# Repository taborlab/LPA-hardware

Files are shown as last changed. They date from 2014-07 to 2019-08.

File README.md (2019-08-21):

# LPA - The Light Plate Apparatus

### Introduction

The LPA is a device capable of illuminating each well of a 24-well plate with two independently time-varying light signals. An electronic board based on the Atmega328 microcontroller reads light intensity values from an SD card and controls the LEDs responsible for illumination.

This repository contains source files, needed to modify the LPA's design. To obtain the minimum necessary files for building and using an LPA, click [here](https://github.com/taborlab/LPA-hardware/releases/download/v1.1/lpa.zip).

If you use the LPA in your research, please cite [Gerhardt K.P., et al. "An open-hardware platform for optogenetics and photobiology." Scientific Reports 6 (2016)](https://www.nature.com/articles/srep35363) and/or [Gerhardt K.P., Castillo-Hair S.M., and Tabor J.T. "DIY optogenetics: Building, programming, and using the Light Plate Apparatus." Methods Enzymol. (2019)](https://www.sciencedirect.com/science/article/pii/S0076687919301338)

### Documentation

The documentation website for the LPA can be found in http://taborlab.github.io/LPA-hardware/.

### Contents:
* BOM: Bill of materials for circuit board and chassis.
* CAD Files: Design files for the different parts of the LPA. This folder contains:
  * 3D Printed Parts: Models of the structural 3D-printed elements of the LPA, in SolidWorks format.
  * Circuit Board: Schematics and layout of the electronic board, in KiCAD format.
  * Gaskets: Diagrams of the rubber gaskets, in DXF (AutoCAD) format.
* Firmware: Source files of the microcontroller's firmware in C++, organized as an Atmel Studio project.
* Calibration: Image analysis script for imager-based LED calibration, in matlab format, and examples.

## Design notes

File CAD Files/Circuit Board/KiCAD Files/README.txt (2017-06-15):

Folder contents
===============

Main files
----------
- lpa.pro : KiCAD project
- lpa.sch : Main schematic diagram
- tlcs_1-3.sch: LED driver schematic diagram
- lpa.kicad_pcb : PCB layout diagram

Libraries
---------
- libraries : folder with schematic diagram part libraries
- LPA_parts.pretty: folder with PCB layout diagram part libraries
- fp-lib-table: file listing the PCB layout diagram part libraries used by this project
- lpa-cache.lib: Part library cache, from which parts can be loaded if not found in the standard libraries.

How to use
==========
Electronic CAD files were created on KiCAD, which can be downloaded from http://kicad-pcb.org/.
To see the CAD files, open KiCAD, go to File -> Open Project, and select "lpa.pro". KiCAD will show a list of files on its left panel. The most important are lpa.sch (schematic diagram) and lpa.kicad_pcb (printed circuit board (PCB) diagram). Double click on each to open.

About gerber files
==================
Gerber files for production were generated according to these instructions: http://docs.oshpark.com/design-tools/kicad/generating-kicad-gerbers/.

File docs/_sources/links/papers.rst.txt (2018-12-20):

Papers which use LPAs
============================

\P. Ramakrishnan, J.J. Tabor **"Repurposing Synechocystis PCC6803 regulatory tool in E. coli."** *ACS Syn. Biol.* 5(7), 733–740 (2016).

K.P. Gerhardt, E.J. Olson, S.M. Castillo-Hair, L.A. Hartsough, B.P. Landry, F. Ekness, R. Yokoo, E.J. Gomez, P. Ramakrishnan, J. Suh, D.F. Savage, J.J. Tabor **"An open-hardware platform for optogenetics and photobiology."** *Sci. Rep.* 6, 35363 (2016).

E.J. Olson, C.N. Tzouanas, J.J. Tabor **"A photoconversion model for full spectral programming and multiplexing of optogenetic systems."** *Mol. Syst. Biol.* 13(4), 926 (2017).

N.T. Ong, E.J. Olson, J.J. Tabor **"Engineering an E. coli Near-Infrared Light Sensor."** *ACS Syn. Biol.* 7(1), 240–248 (2018).

N.T. Ong, J.J. Tabor **"A miniaturized E. coli green light sensor with high dynamic range."** *Chembiochem.* 19, 1255-1258 (2018).

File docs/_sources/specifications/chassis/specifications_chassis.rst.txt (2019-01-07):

-----------------------------
Chassis
-----------------------------

Detailed photographs of 3D printed LPA parts
------------------------------------------------

.. figure:: chassis_1.png
   :scale: 30%
   :figwidth: 100%

.. figure:: chassis_2.png
   :scale: 30%
   :figwidth: 100%

   Bottom and top perspectives of 3D printed LPA parts are shown.
   These include (a) mounting plate, (b) LED spacer, (c) cell culture plate adapter, and (d) device lid.
   If shaking culture is required, the mounting plate platform holes must be designed for a particular platform.
   The two mounting plates shown were designed for two different shaking platforms.

Photographs of LPA gaskets
------------------------------------------------

.. figure:: gaskets.png
   :scale: 30%
   :figwidth: 100%

   LPA gaskets are laser cut (see Supplementary Method on Laser cutting gaskets) from nitrile sheets (Supplementary Table S6) and prevent light leakage and crosstalk between wells.
   (a) The (i) circuit board, (ii) LED spacer, and (iii) cell culture plate adapter gaskets are shown.
   Gasket names are based on the layer they lay atop.
   Though not necessary, we found it convenient to superglue on the cell culture plate adapter gasket.
   (b) A plate adapter gasket which has been laser cut with patterns centered with wells of the culture plate.

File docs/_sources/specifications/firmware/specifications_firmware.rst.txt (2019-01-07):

Firmware
==========================

Introduction
--------------------------

The LPA firmware is an embedded program written in C for the ATmega328 microcontroller. It performs the following main functions:

  a)	Reads an LPF file from an SD card, connected to the microcontroller via a Serial Peripheral Interface (SPI).
  b)	Reads light intensity (“grayscale”) values from the LPF file.
  c)	Updates the intensity of a set of LEDs under control of TLC5941 drivers, by transferring the appropriate grayscale values via SPI.

The firmware has been divided in different modules that perform separate functions. All the relevant variables inside a module are named as <module_name>_<variable_name>. Functions are named in a similar format. Modules are written such that, when possible, the assignment of hardware resources is defined by a “configuration” step, controlled by a separate config.h file that is included during compilation. This facilitates porting the individual modules to different projects, or transferring this project to a similar microcontroller.

In this section, we will describe the high-level behavior of the firmware main program, the contents of each module, and the config.h file.

States of the Firmware Program
---------------------------------------------

.. figure:: states.png
   :scale: 20%
   :figwidth: 100%

   In this diagram, rounded squares denote states, rounded squares with double edges denote terminal states, and arrows denote transitions. The circle labeled as START denotes the state of the program upon booting.

The LPA will often need to respond differently to the same stimuli, especially under error conditions. This is best managed by modeling the system as a finite state machine, in which the device’s behavior is a function of both the inputs and the current state. In the firmware, the current state is contained in a single variable. Supplementary Table S4 enumerates the different states of the device, and Supplementary Fig. S14 shows the transition diagram between different states. Each pattern displayed by the status LEDs corresponds directly to each state (Supplementary Tables S3 and S4).

TLC5941 Driver module
----------------------------------------

The TLC5941 driver module is available as a separate project (https://github.com/castillohair/Tlc5941_library). This module is heavily based on the “Demystifying the TLC5940” book10, with a few additions to make the library work with the TL5941 instead of the TL5940, the Atmega328 USART module instead of the SPI module, among others. In short, this module incorporates functions to:

-	Initialize the TLC5941
-	Set grayscale values, one at a time or all at once.
-	Change dot correction values, one at a time or all at once.

In addition, several precompiler flags are available to define the pins used to interact with the TLC5941. These can be changed inside “config.h” file without modifying the library’s source code.

MsTimer Module
---------------------------------

The MsTimer (millisecond timer) module incorporates functions to define a timer that calls a set of functions (“callbacks”) periodically, with a period specified in milliseconds. This module uses the Atmega’s Timer1 to generate interrupts via compare events. The module incorporates functions to

-	Initialize the relevant registers of Timer1.
-	Add callbacks and their respective periods in milliseconds.
- Start and stop the module.

StatusLeds Module
----------------------------

The StatusLeds module is a simple module that abstracts the toggling of status LEDs on the board. It incorporates functions to

-	Initialize the pins that control the status LEDs.
-	Set the status of an LED to on or off.
-	Toggle an LED to the opposite state.

SD Card Reading
-------------------------

SD card reading is performed using the Arduino SD card library. For details on how to set the library before compiling, refer to the Supplementary Method on firmware programming.

The config.h File
----------------------

The config.h file should be included during compilation of every file associated with the project. By doing this, preprocessor directives defined in config.h (i.e. #define instructions) replace the ones defined in the modules by default. This allows us to override the default behavior of the module without changing the code, a procedure called “configuration”.

Additionally, the firmware has been made such that an arbitrary number of LEDs in any arrangement is possible. The number of LEDs is specified through the number of LED drivers (Tlc5941_N), whereas the arrangement is specified as a constant array (well2channel). The arrangement corresponding to the 24-well LPA is included by default, but a file called “config_96.h”, which illustrates the configuration for a hypothetical 96-well LPA, is also included.

firmware.cpp
-------------------------

This file contains the main function of the firmware (main()). Other important parts are:

-	Variables dotCorrectionValues[] and grayscaleCalibration[], which store dot correction and grayscale calibration values after reading them from files dc.txt and gcal.txt in the SD card.
-	Definitions of constants corresponding to the states (Supplementary Table S4, all the #define System_<state_name> instructions), a variable containing the current state (System_state), and functions to evaluate the state (System_SetState(), System_IsState() and System_IsNotState()).
-	A function to update the LPA LEDs, UpdateLeds().
-	A function to update the status LEDs based on the current state, UpdateStatusLeds().

In short, the main function does the following:

1.	Initializes the TLC5941 module.
2.	Initializes the MsTimer and the StatusLeds module.
3.	Initializes the SD card module.
4.	Reads and parses both dc.txt and gcal.txt files.
5.	Opens the “program.lpf” file.
6.	Reads the time step size specified in “program.lpf”, and initializes timers with MsTimer so UpdateLeds() is called with the appropriate frequency.
7.	Waits for UpdateLeds() to be called.
8.	Reads a new set of intensity values from the SD card and places them on a buffer, such that UpdateLeds() can send them to the TLC5941s when it is called again.
9.	Repeat from 6 until “program.lpf” file has been read completely.

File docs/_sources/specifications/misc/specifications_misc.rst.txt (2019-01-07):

-----------------------------
Miscellaneous
-----------------------------

LPA power connections
-----------------------------------

.. image:: power_connections.png
   :scale: 30%

The LPA requires a continuous 5V DC power supply and power connections must be reinforced during experiments to prevent movement and mechanical stress, particularly for shaking culture.
Standard laboratory tape can be used as shown to secure power connections and free wires.

Photographs of 3D printed auxiliary parts
------------------------------------------------

.. image:: auxillary.png
   :scale: 30%

The LED socket aligner is used to align and secure LED sockets to the circuit board during soldering (see Supplementary Method on circuit board fabrication and assembly).
(b) The probe adapter is used to position and align the spectrometer probe while making LED intensity measurements (see Supplementary Method on LED calibration).
Top and Bottom versions of the part are used for alignment with Top and Bottom LEDs, respectively.
(c) The flow tube holder holds and spaces flow cytometry tubes with the same geometry as wells from the cell culture plate.
The holder allows easy transfer of samples from the culture plate to flow tubes using a multichannel pipettor (LT12-1200, Ranin).
The part is snapped together and epoxied from three separately printed parts: top rack, bottom rack, and pegs.

Close-up photograph of LED and LED socket friction fit
----------------------------------------------------------

.. image:: led_socket.png
   :scale: 30%

LEDs are positioned, aligned, and held in place by mating with an LED socket (Supplementary Table S1) via friction fit.
This fixture system allows LEDs in the LPA to be easily be installed, removed, and reconfigured.

Photograph and schematic of culture plate used in the LPA
----------------------------------------------------------------

.. image:: culture_plate.png
   :scale: 30%

\(a) Top and bottom views of the 24-well culture plate (AWLS-303008, ArcticWhite LLC) used in the LPA.
\(b) A schematic (adapted from supplier schematic) showing the important dimensions (mm) of the plate.
The original schematic can be requested from ArcticWhite LLC.

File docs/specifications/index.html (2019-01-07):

- Docs »
- Specifications
- View page source

# Specifications¶

Warning

The following specifications describe the LPA v1.0. Changes to later LPA versions are described in the releases section of the github repo.

- Electronics
  - Detailed circuit board photographs
  - Circuit board SD-card reader stage schematic
  - Circuit board microcontroller stage schematic
  - Circuit board LED driver stage schematic
  - Circuit board power stage schematic
- Firmware
  - Introduction
  - States of the Firmware Program
  - TLC5941 Driver module
  - MsTimer Module
  - StatusLeds Module
  - SD Card Reading
  - The config.h File
  - firmware.cpp
- Chassis
  - Detailed photographs of 3D printed LPA parts
  - Photographs of LPA gaskets
- Miscellaneous
  - LPA power connections
  - Photographs of 3D printed auxiliary parts
  - Close-up photograph of LED and LED socket friction fit
  - Photograph and schematic of culture plate used in the LPA

Next Previous

© Copyright 2016, Tabor Lab

Built with Sphinx (http://sphinx-doc.org/) using a theme (https://github.com/rtfd/sphinx_rtd_theme) provided by Read the Docs (https://readthedocs.org).

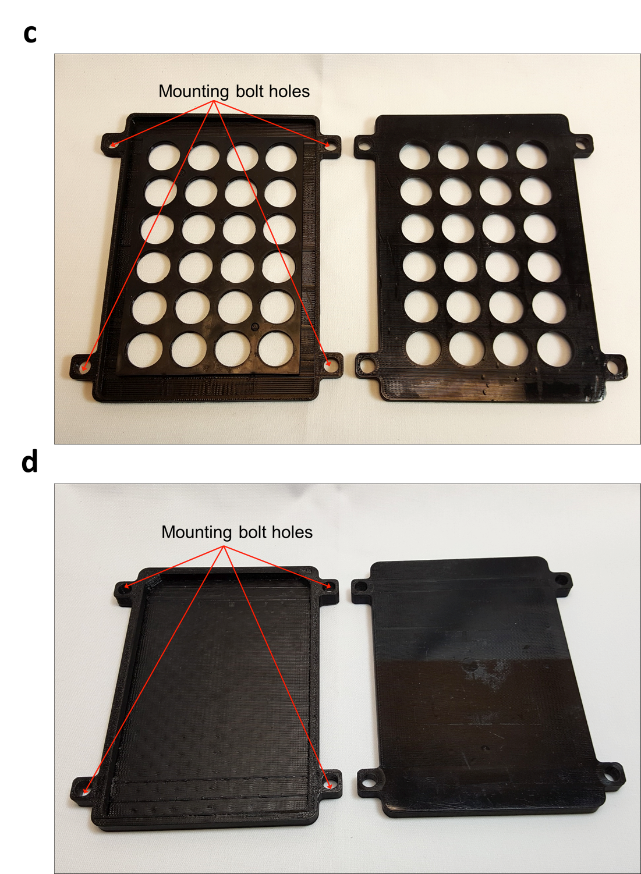
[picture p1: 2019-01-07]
docs/_images/chassis_2.png

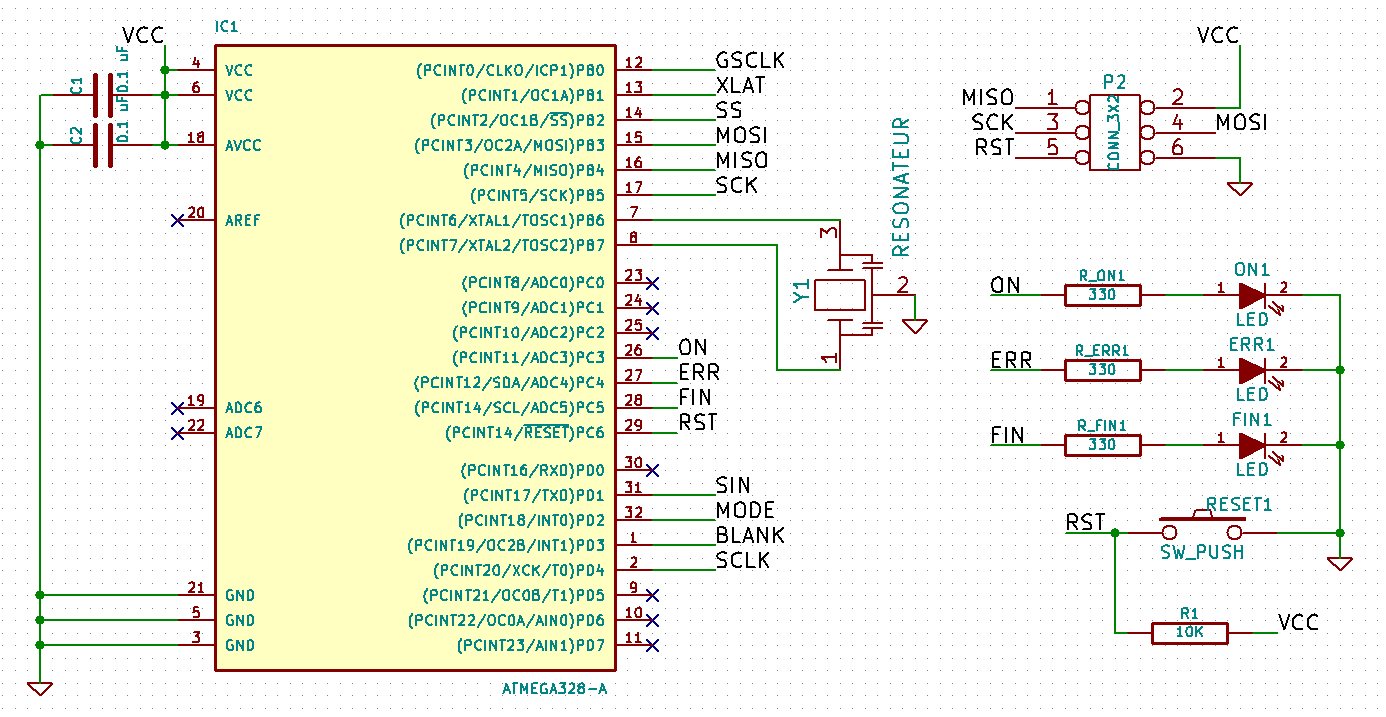
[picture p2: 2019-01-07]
docs/_images/microcontroller.png

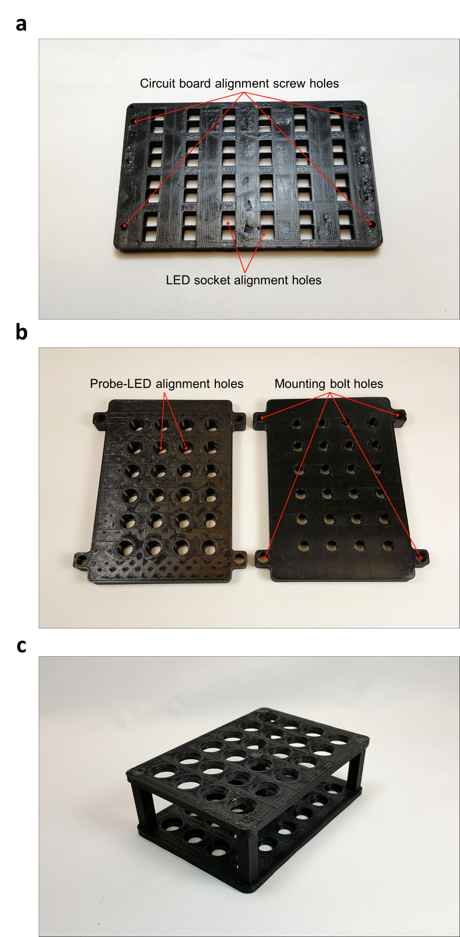
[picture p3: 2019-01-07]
docs/_images/auxillary.png

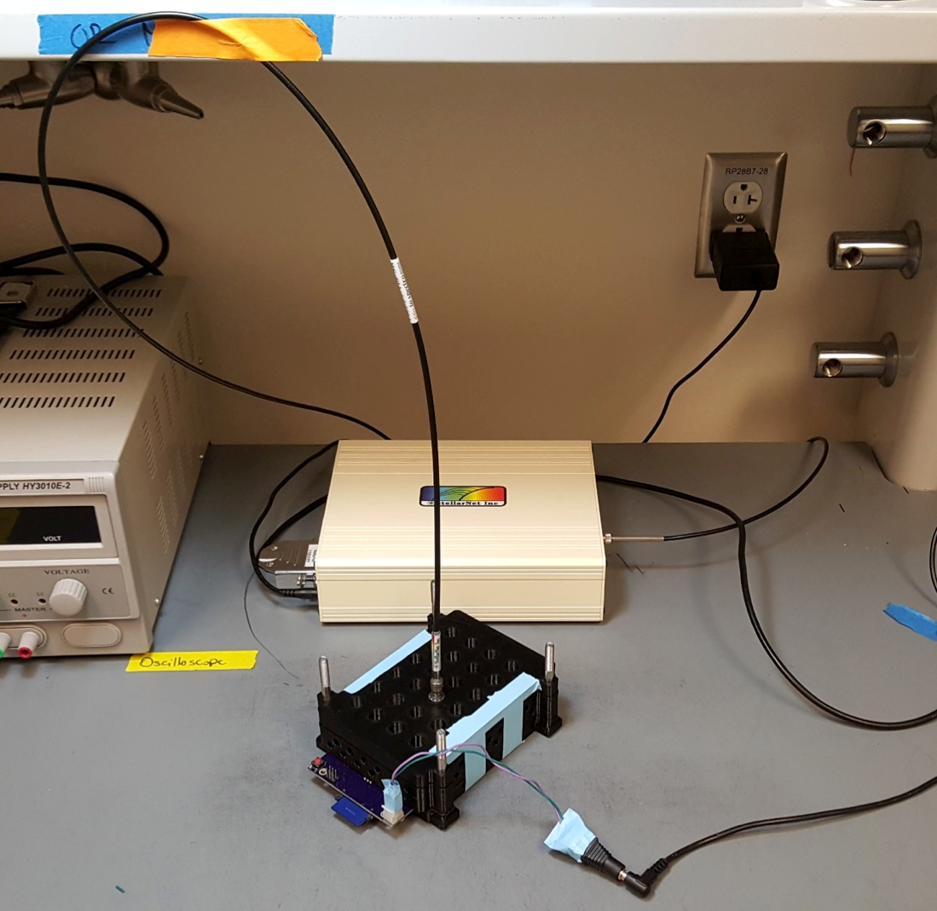
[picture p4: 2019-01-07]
docs/_images/probe.png

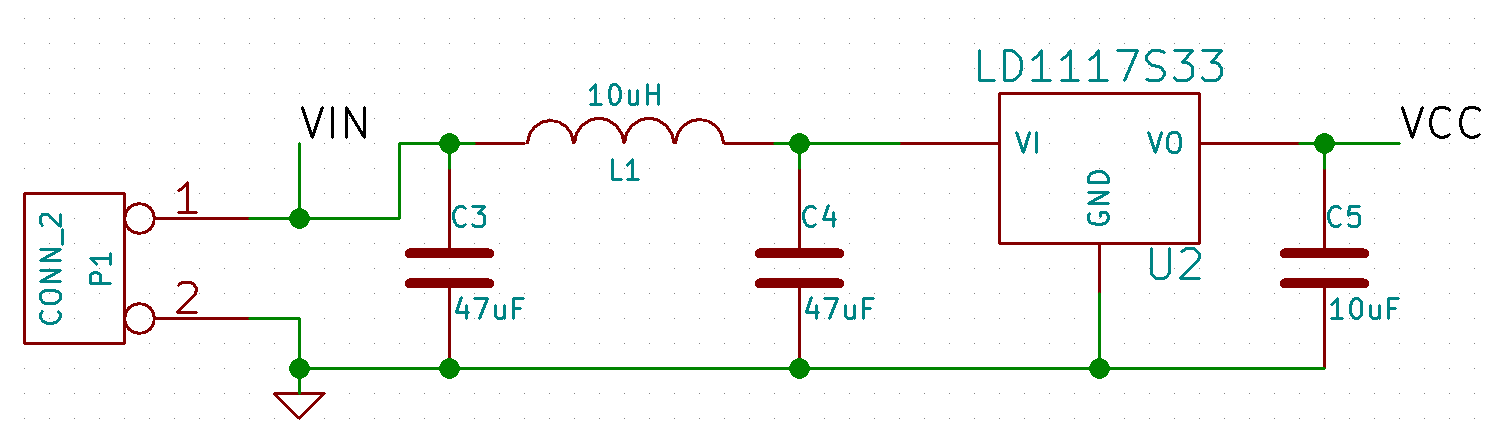
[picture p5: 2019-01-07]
docs/_images/power_stage.png

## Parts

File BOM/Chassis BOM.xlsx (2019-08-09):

Line Item | Description | QTY | Manufacturer | Mfg P/N # | Distributor | Distributor P/N # | Note
1 | 24-well Culture Plate | 1 | ArcticWhite LLC | AWLS-303008 | ArcticWhite LLC | AWLS-303008 | 24-well, opaque w/transparent bottom. Reuseable.
2 | 70 mm bolt | 4 | NA | NA | McMaster-Carr | 91287A252 | 70mm/6mm(10mm hex)/M6 (Length/Diameter/Thread)
3 | Wing nut | 4 | NA | NA | McMaster-Carr | 92124A530 | M6 x 1mm thread. Black nitrile.
4 | Adhesive foil | 1 | NA | NA | VWR | 60941-126 | Disposed every experiment.
5 | Nitrile rubber sheet | ~0.5 | E. James and Co. | 5340-1/32HGA | Grainger | 1DPZ3 | 12''x12''x1/32'' Length/Width/Thickness. Half sheet enough for one set of gaskets.
6 | 5V wall mount switching power supply | 1 | Cincon | TRG1505-A-11E03-Level-VI | Mouser | 418-TRG1505A11E03VI | 90-264V AC to DC wall adapter. Many other possibilities.

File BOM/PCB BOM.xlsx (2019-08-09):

Line Item | Description | QTY | Ref Des | Manufacturer | Mfg P/N # | Distributor | Distributor P/N # | Note
1 | IC MCU 8BIT 32KB FLASH 32TQFP | 1 | IC1, | Atmel | ATMEGA328-AU | digikey | ATMEGA328-AURCT-ND
2 | LED Driver IC 16 Output Linear Shift Register 80mA 28-HTSSOP | 3 | U3, U4, U5 | Texas Instruments | TLC5941PWP | digikey | 296-18617-5-ND
3 | CRYSTAL 16.0000MHZ 10PF SMD | 1 | X1 | CTS-Frequency Controls | 403C11A16M00000 | digikey | CTX847CT-ND
4 | RES SMD 10K OHM 5% 1/8W 0805 | 2 | R1, R2 | Panasonic Electronic Components | ERJ-6GEYJ103V | digikey | P10KACT-ND
5 | RES SMD 2.2K OHM 0.5% 1/10W 0805 | 3 | R3, R4, R5 | Susumu | RR1220P-222-D | digikey | RR12P2.2KDCT-ND
6 | RES SMD 330 OHM 5% 1/8W 0805 | 3 | R_ERR1, R_FIN1, R_ON1 | Samsung Electro-Mechanics America, Inc. | RC2012J331CS | digikey | 1276-5519-1-ND
7 | Multilayer Ceramic Capacitors MLCC - SMD/SMT 50V 12 pF 0.01 1% Tol | 2 | C9, C10 | AVX | 08055U120FAT2A | mouser | 581-08055U120FAT2A
8 | CAP CER 0.1UF 50V Y5V 0805 | 6 | C1, C2, C6, C7, C8, C11 | Samsung Electro-Mechanics America, Inc. | CL21F104ZBCNNNC | digikey | 1276-1007-1-ND
9 | CAP ALUM 100UF 20% 35V SMD | 1 | C3 | Nichicon | UWT1V101MCL1GS | digikey | 493-2203-1-ND
10 | CAP ALUM 470UF 20% 10V SMD | 1 | C5 | Nichicon | UWT1A471MNL1GS | digikey | 493-2169-1-ND
11 | FIXED IND 150UH 700MA 988 MOHM | 1 | L1 | TDK Corporation | VLS6045EX-151M | digikey | 445-173042-1-ND
12 | DIODE SCHOTTKY 45V 2A SOD123FL | 1 | D49 | ON Semiconductor | NRVTS245ESFT1G | digikey | NRVTS245ESFT1GOSCT-ND
13 | IC REG BUCK 3.3V 2A 8SOIC | 1 | U2 | Diodes Incorporated | AP1509-33SG-13 | digikey | AP1509-33SGDICT-ND
14 | SWITCH TACTILE SPST-NO 0.05A 12V | 1 | RESET1 | C&K Components | PTS645SK43SMTR92 LFS | digikey | CKN9084CT-ND | Trivial DIY solder
15 | CONN SD CARD PUSH-PUSH SMD | 1 | U1 | Amphenol Commercial Products | 10067847-001RLF | digikey | 609-3956-2-ND
16 | LED GREEN DIFFUSED 0805 SMD | 1 | ON1 | OSRAM Opto Semiconductors Inc. | LG R971-KN-1 | digikey | 475-1410-1-ND
17 | LED RED DIFFUSED 0805 SMD | 1 | ERR1 | OSRAM Opto Semiconductors Inc. | LH R974-LP-1 | digikey | 475-1415-1-ND
18 | LED YELLOW DIFFUSED 0805 SMD | 1 | FIN1 | OSRAM Opto Semiconductors Inc. | LY R976-PS-36 | digikey | 475-2560-1-ND
19 | CONN HDR BRKWAY .100 40POS VERT | 0.15 | P2 | TE Connectivity AMP Connectors | 9-146282-0 | mouser | A34253-40-ND | Trivial DIY solder
20 | DC Power Connectors 2.0MM DIA,HI-CURRENT LOCKING TYPE | 1 | CON1 | Kycon | KLDHCX-0202-A-LT | mouser | 806-KLDHCX-0202-A-LT | Trivial DIY solder
21 | LED SOCKET VERTICLE MOUNT | 48 | LED1-48 | Visual Communications Company | PCV_220-ND | digikey | PCV_220 | DIY solder strongly reccommended, not included in component placement file

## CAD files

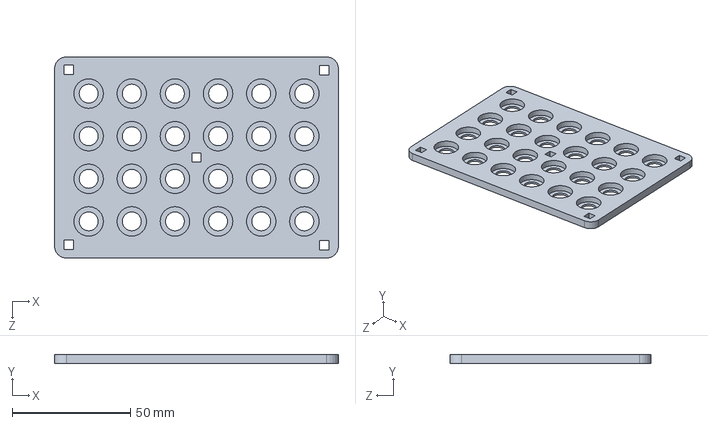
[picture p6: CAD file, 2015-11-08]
CAD Files/3D Printed Parts/auxiliary parts/flow tube holder/flow_tube_holder_v3_top.SLDPRT
120.0 x 4.00 x 85.0 mm

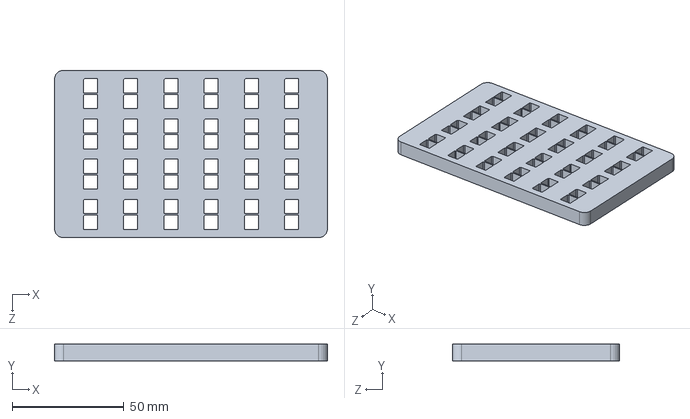
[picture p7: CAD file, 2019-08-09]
CAD Files/3D Printed Parts/auxiliary parts/led socket aligner/LED_socket_aligner_xomv0.6.SLDPRT
122.1 x 7.50 x 74.8 mm

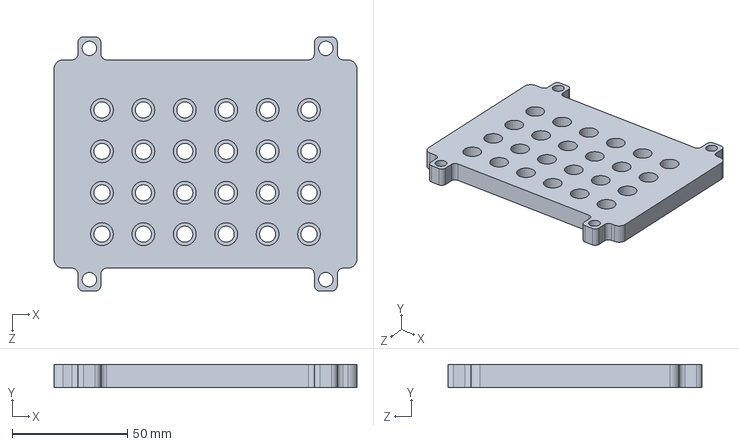
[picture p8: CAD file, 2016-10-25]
CAD Files/3D Printed Parts/auxiliary parts/probe adapter/probe_adapter_xomv1.1_top.SLDPRT
131.7 x 10.0 x 110.6 mm

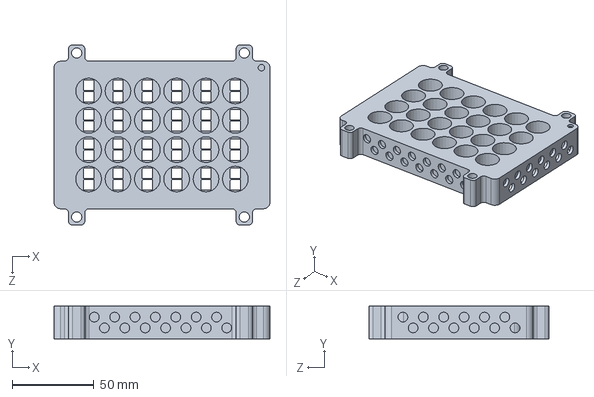
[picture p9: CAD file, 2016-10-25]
CAD Files/3D Printed Parts/LPA parts/LED spacer/LED_spacer_xomv0.25.SLDPRT
132.5 x 20.0 x 110.6 mm

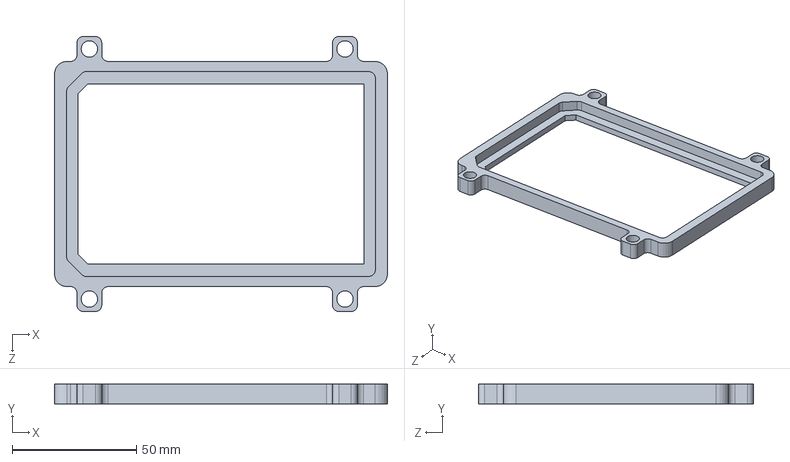
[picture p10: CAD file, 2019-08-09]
CAD Files/3D Printed Parts/LPA parts/lid/frame type/plate_lid_frame_xomv3.2.SLDPRT
133.9 x 8.00 x 110.6 mm

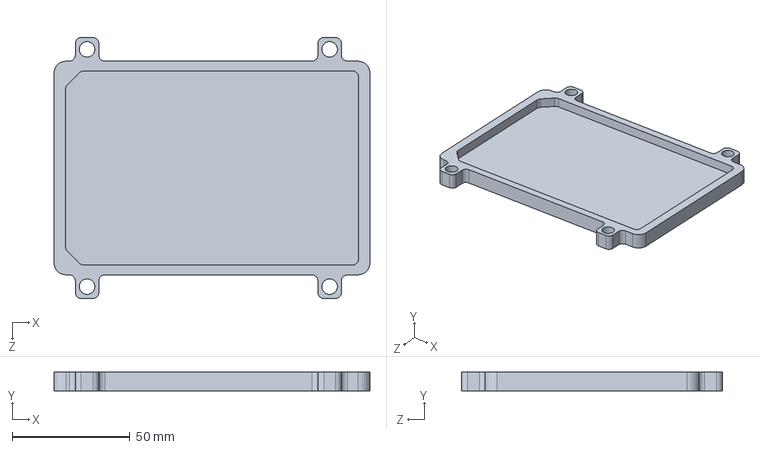
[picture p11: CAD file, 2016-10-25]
CAD Files/3D Printed Parts/LPA parts/lid/solid/plate_lid_xomv3.2.SLDPRT
133.9 x 8.00 x 110.6 mm

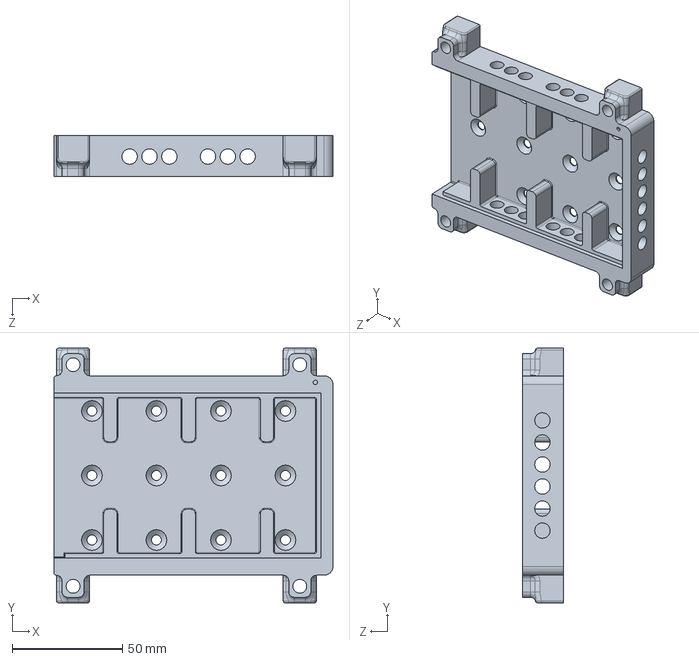
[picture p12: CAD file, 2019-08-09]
CAD Files/3D Printed Parts/LPA parts/mounting plate/mounting_plate_xomv0.5.SLDPRT
126.5 x 115.4 x 18.4 mm

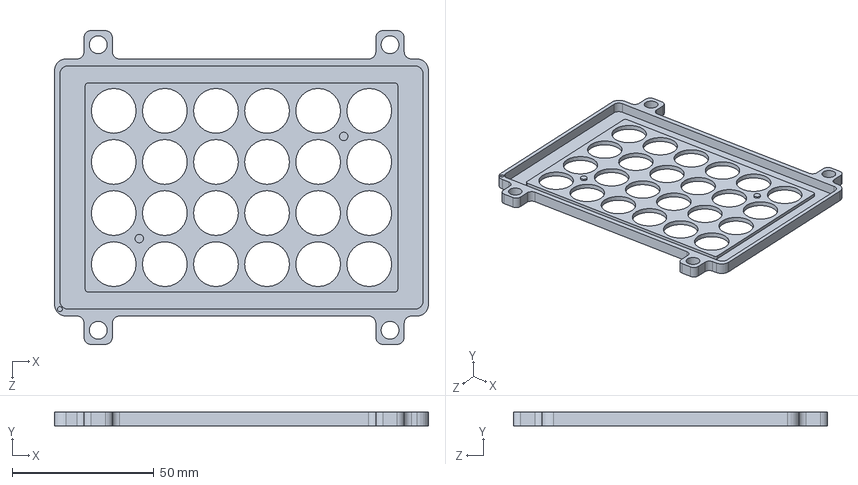
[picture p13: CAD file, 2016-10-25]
CAD Files/3D Printed Parts/LPA parts/plate adapter/plate_adapter_xomv3.11.SLDPRT
131.7 x 5.00 x 110.6 mm

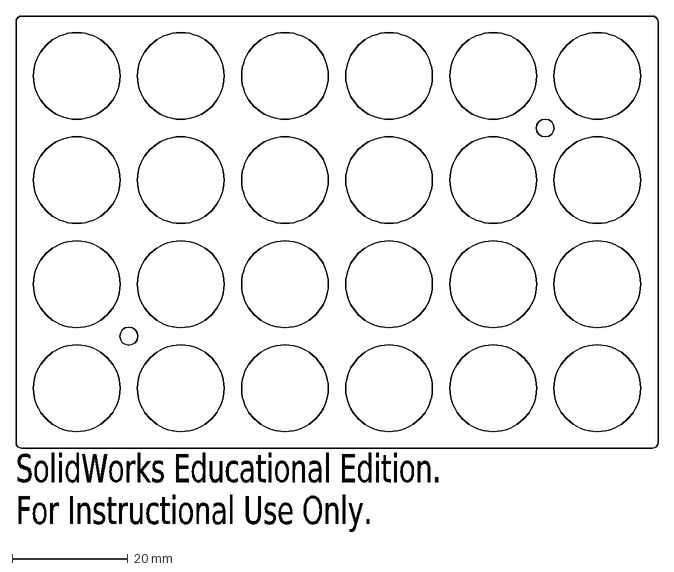
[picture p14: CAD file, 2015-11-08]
CAD Files/Gaskets/adapter_plate_gasket_v1.32.DXF
SolidWorks Educational Edition.
For Instructional Use Only.

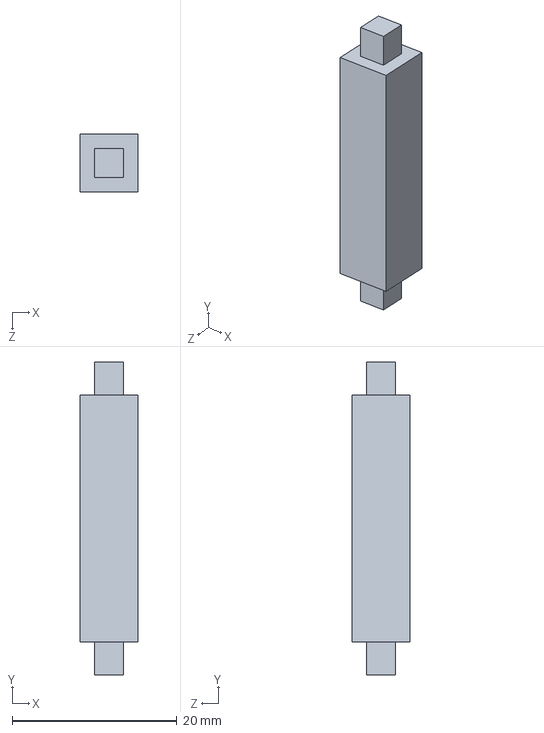
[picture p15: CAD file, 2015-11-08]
CAD Files/3D Printed Parts/auxiliary parts/flow tube holder/flow_tube_holder_v3_peg.SLDPRT
7.00 x 38.0 x 7.00 mm

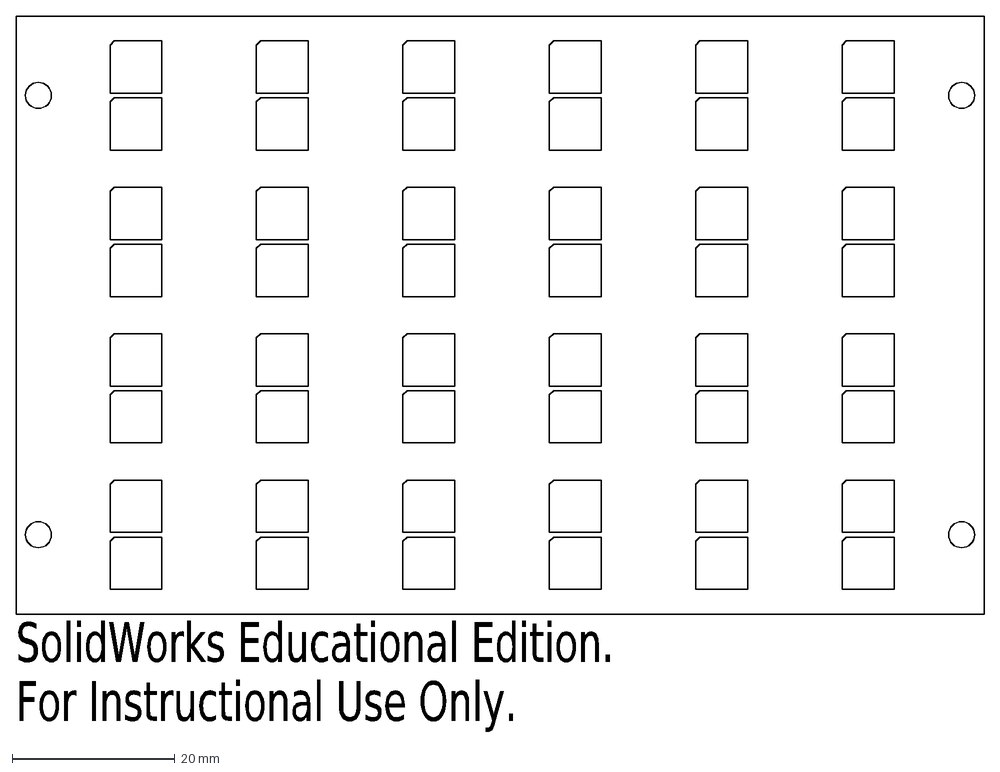
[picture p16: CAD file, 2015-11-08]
CAD Files/Gaskets/pcb_spacer_gasket_v1.0.DXF
SolidWorks Educational Edition.
For Instructional Use Only.

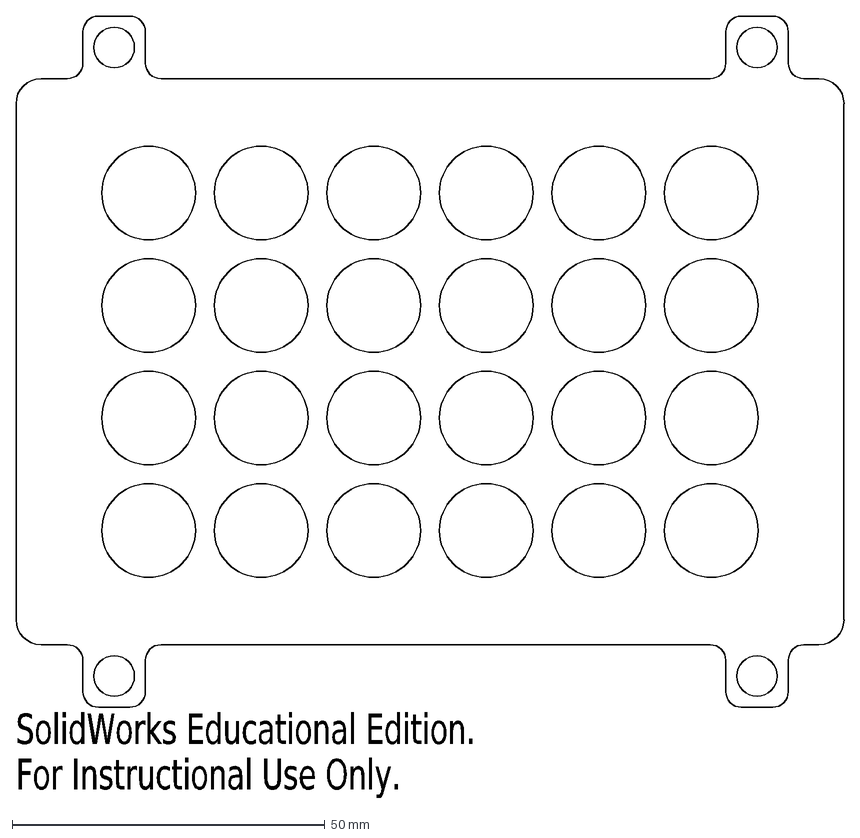
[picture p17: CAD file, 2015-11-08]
CAD Files/Gaskets/spacer_adapter_gasket_v1.22.DXF
SolidWorks Educational Edition.
For Instructional Use Only.

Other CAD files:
CAD Files/3D Printed Parts/auxiliary parts/probe adapter/probe_adapter_xomv1.1_bot.SLDPRT
CAD Files/3D Printed Parts/auxiliary parts/flow tube holder/flow_tube_holder_v3_bottom.SLDPRT
CAD Files/3D Printed Parts/LPA parts/LED spacer/LED_spacer_xomv0.25.STL
CAD Files/3D Printed Parts/LPA parts/lid/frame type/plate_lid_frame_xomv3.2.STL
CAD Files/3D Printed Parts/LPA parts/lid/solid/plate_lid_xomv3.2.STL
CAD Files/3D Printed Parts/LPA parts/mounting plate/mounting_plate_xomv0.5.STL
CAD Files/3D Printed Parts/LPA parts/plate adapter/plate_adapter_xomv3.11.STL
CAD Files/3D Printed Parts/auxiliary parts/flow tube holder/flow_tube_holder_v3_bottom.STL
CAD Files/3D Printed Parts/auxiliary parts/flow tube holder/flow_tube_holder_v3_peg.STL
CAD Files/3D Printed Parts/auxiliary parts/flow tube holder/flow_tube_holder_v3_top.STL
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

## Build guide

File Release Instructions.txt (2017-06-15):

The following files should be regenerated before a new release/commit to master, in order to avoid mismatches between source files and files intended for production:

- "CAD Files/3D Printed Parts": All .STL files should be regenerated from SolidWorks files.
- "CAD Files/Circuit Board": All files in "Production Files" folder should be regenerated from KiCAD files. Gerber and drill files have been generated following the instructions here: http://docs.oshpark.com/design-tools/kicad/generating-kicad-gerbers/. Files "LPA_BOM.xlsx" and "LPA_component.xlsx" should be remade by hand.
- "Firmware": File "firmware.elf" in the "Compiled" folder should be regenerated from the source in the "Source" folder. File "fuses.txt" should be directly copied from the "Source" folder.

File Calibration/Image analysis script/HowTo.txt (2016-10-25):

This is a HowTo for running the Image analysis calibration script(s). Carefully read the supplementary procedure on "Calibrating LEDs" (Supplementary Procedure 8) before proceeding. Example images, which 'analysis.m" and "calibration.m" are preconfigured to run with, and example output files can be inspected in the "examples" folder. Visit taborlab.rice.edu for updates.

1. You should at this point have two .tif images for an LED set within a device: (1) normal orientation and (2) transposed orientation. The images should have the same name, but with "_T" appended to the transposed image name, e.g. "round1.tif" and "round1_T.tif". Move these image files to a folder in the same directory as the script files.  Open "analysis.m".

2. Specify, in single quotes the following:
	a. the path for the images on line 3, after "folder = ". e.g. "folder = 'example/arya_678nm_bot_150802/'"
	b. the image root file name on line 4, after "folder ". e.g. "im_filename = [folder 'round1'];"
Run "analysis.m".

3. Two .csv files appended with "_raw" and "_rel" should be automatically generated in your image directory. These .csv files contain the intensity values (arbitrary or relative units) for each LED. The next script to run, "calibration.m" uses these files. Open "calibration.m".

4.  Specify the following:
	a. on line 12, the current calibration round (going through multiple rounds of calibration can improve results). e.g. "calibration_round = 1;"
	b. on line 14-15, the image file path. 
		e.g. "folder_ch1 = 'example/arya_678nm_bot_150802/';
		     "folder_ch2 = 'example/arya_678nm_bot_150802/';"
	c. on line 17, the name of the "_raw" LED intensity .csv file. e.g. "filename = [strtrim(folders(channel,:)) 'round1_raw.csv'];"
	d. there is the optional abilitiy to specify which "channel" (ch1/ch2) the LEDs are in the device. 
Run "calibration.m".

5. A new "calibration" .csv file should be generated which contains the grayscale values to assign each LED. Replace the old grayscale values with these new values in your .gs file. In the first round of calibration, it is assumed all grayscale value were 255. In subsequent rounds, the script will assume the current grayscale values are the values generated in the previous round.

6. Take images, as before, with these new grayscale values. Use "analysis.m" to verify satisfactory results. Iterate if necessary.

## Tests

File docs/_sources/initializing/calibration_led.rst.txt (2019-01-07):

LED calibration
===============

The purpose of this procedure is to describe our method for calibrating LEDs for experiments with LPAs. We calibrate devices to produce the same photon flux across LEDs. We use two methods to calibrate LEDs depending on the type of LED configuration: an image analysis method for calibrating LEDs of the same wavelength (e.g. twenty-four 647 nm LEDs), and a probe spectrometer method for calibrating LEDs of different wavelength (e.g. action spectrum LED sets). Before calibration, it is critical that LEDs be firmly pushed down into their sockets to ensure proper LED height and alignment. For both methods the device is assembled from the mounting plate up to the circuit board-spacer module. During calibration only one channel, i.e. only one LED per well, can should be on at a time.

LED compensation is achieved by setting the grayscale and dot correction for each LED. These values are distinct from the intensity values set in Iris. Grayscale and dot correction values are stored on the device’s SD card as files “gcal.txt” and “dc.txt”, respectively, and must be space delimited integers from 0-255 and 0-63, respectively. Coarse adjustments can be made by setting the LED dot correction, while fine adjustments can be made setting the gray scale value.

Note that the grayscale adjustment reduces the resolution of intensities which can be achieved. With a maximum grayscale adjustment value of 255, there are 4096 intensity levels which can be programmed. However, the number of intensity levels available reduces proportionally to the grayscale adjustment value. For example, if the grayscale adjustment value is set to 100, there will only be 4096 * 100/255 = 1606 programmable intensity levels. This reduction in resolution means that when programming values in Iris, multiple programmed values will correspond to the same resulting intensity. Continuing the example, a programmed value of 4095 will be converted to 1606 internally in the LPA, while the programmed values of 4095, 40945, and 4093 will all correspond to 1605.

Image analysis method:
----------------------------
We developed an image analysis method for calibrating LEDs of the same wavelength to one another. The method is relatively fast and utilizes a MATLAB script (Supplementary Files) which analyzes pixel intensity of images taken top-down of the device while all LEDs in a channel (top row or bottom row) are set to a constant intensity. We had success taking top-down images of devices in an enclosed gel-imager (FluorChem FC2, Alpha Innotech) which blocks out ambient light. Briefly, we set all LEDs within a channel to a single Iris intensity below the saturation threshold (but ≥ 100, see above) of the gel imager camera. To reduce the spatial structure of the LED light we place three sheets of diffuser paper (#3008, Rosco) atop the LED spacer and add the plate adapter. The device is centered below the camera and powered on. Finally, images (60ms exposure) are taken at 0° (well 1 in top corner) and at 180° (well 1 in bottom right, i.e. transposed). Images are then analyzed by the MATLAB script. A README HowTo which contains details of running the script as well as example images and script outputs is available in the image analysis Supporting FileSupplementary Files. After calibration by image analysis, photon flux is determined by measuring a subset (≥ five LEDs) of the calibrated LEDs with a probe spectrometer (see below).

**LED outputs before and after image analysis calibration**

.. figure:: calibration.png
   :scale: 55%
   :figwidth: 100%

   Representative comparison of LED intensity output before and after the image analysis calibration procedure (see Supplementary Method on LED calibration). (a) Heatmap showing distribution of 678 nm LED intensities prior to calibration (CV = 7.78%). (b) Heatmap showing intensity distribution of the same LEDs as in (a), after the image analysis calibration (CV = 0.55%), in which LEDs are scaled to the dimmest LED. (c) Histogram of LED intensity outputs from (a) and (b). LED intensities are measured as the sum of pixel intensity inside the LPA well containing the LED.

Probe spectrometer method:
------------------------------

The image analysis method does not work for calibrating LEDs of different wavelength to each other due to the camera’s differential sensitivity to different wavelengths of light.
For action spectra LED configurations, we directly measure the photon flux of each LED using a probe spectrometer (StellarNet Inc, photodetector: EPP2000 UVN-SR-25LT-16, probe: F600-UV-VIS-SR, software: SpectraWiz) ((Supplementary Fig. S20), (SpectraWiz Software) and 3D printed probe adapter (Supplementary Fig. S7b).
The probe adapter is designed to align the probe directly above an LED within a well at the same height as the bottom of the cell culture plate*.
During calibration, the device is programmed with a constant, sub-saturating intensity (usually between 10-20μmol m-2 s-1) across each LED being calibrated. A typical probe calibration workflow is as follows:

1. Coarse adjust LED output to the approximate desired intensity by measuring photon flux while adjusting dot correction. Do this one LED at a time.
2. Measure photon flux for all LEDs. The measurement can be performed using the peak-fitting function within SpectraWiz, or can be made by saving the spectrum and calculating the integral of the peak from the spectral flux data.
3.	Calculate:

GS_desired =  Intensity_desired/Intensity_current  GS_current

and enter the desired gray scale values for each LED.

4. Repeat steps 2-3 until desired photon flux and variance across LEDs is achieved.

**Photograph of light intensity probe measurement setup.**

.. figure:: probe.png
   :scale: 45%
   :figwidth: 100%

   An example of the setup used to make LED intensity measurements with the probe spectrometer is shown. The LPA is assembled from the mounting plate to LED spacer & gasket and the probe adapter is installed as the top layer.
   Tape is used to compress layers together. The probe fits snuggly within the probe-LED alignment holes and is positioned directly above the LED being measured.
   Instructions for measurements and calibration with the probe spectrometer can be found in the Supplementary Method on LED calibration.

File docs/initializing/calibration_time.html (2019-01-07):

- Docs »
- Initializing a new device »
- LPA time step calibration
- View page source

# LPA time step calibration¶

Warning

This procedure should only be performed with LPA v1.0. Later versions use a different resonator which do not require time step calibration.



The firmware project with the config.h file open, showing the stepSizeScaling parameter used to perform LPA time calibration.

The resonator (535-10008-1-ND) used with the LPA v1.0 design has a tolerance which produces a small time error. For long experiments, this can become significant. To correct for this time scaling, one can adjust the stepSizeScaling (Supplementary Fig. S12) in the firmware config.h file. This parameter (set to 1.0 by default) will scale the time steps of the programs run on the device. The correction is best done by running a long (12 h <) program on the device and noting (by indicator LEDs or well LEDs) the actual length of the experiment. The stepSizeScaling then should be set to the ratio of desired time to actual time.

Next Previous

© Copyright 2016, Tabor Lab

Built with Sphinx (http://sphinx-doc.org/) using a theme (https://github.com/rtfd/sphinx_rtd_theme) provided by Read the Docs (https://readthedocs.org).

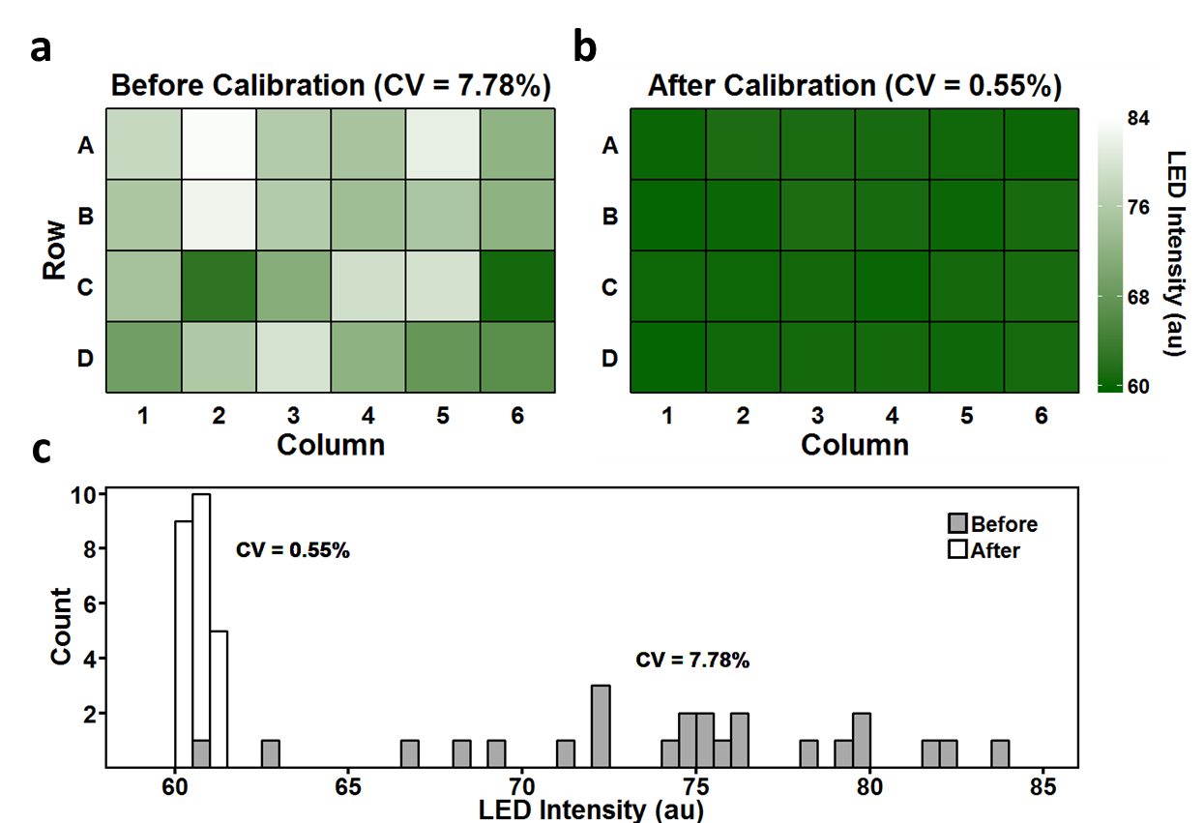
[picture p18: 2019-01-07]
docs/_images/calibration.png

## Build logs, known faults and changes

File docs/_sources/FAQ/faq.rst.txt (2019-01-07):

FAQ
======================
Roughly in order of importance and how frequently asked.

| **Q1: What should I do if my question isn't addressed in this FAQ?**
| A1: Check the `issues <https://github.com/taborlab/LPA-hardware/issues>`_ (including `closed issues <https://github.com/taborlab/LPA-hardware/issues?q=is%3Aissue+is%3Aclosed>`_) or raise a new issue on github.

| **Q2: Where can I find the latest version of the** ``LPA`` **hardware and firmware?**
| A2: Check the `releases <https://github.com/taborlab/LPA-hardware/releases>`_ tab in the github repo for the latest version.

| **Q3: What is the difference between the latest** ``LPA`` **version and the version in the publication (v1.0)?**
| A3: Changes are described in the notes with each release.

| **Q4: Are the electrical components used with** ``LPA v1.0`` **the same/compatible with the latest** ``LPA`` **version?**
| Q4: As of ``LPA v1.1``, most of the components are the same but some have changed. With each release, the bill of materials (BOM) is updated.

| **Q5: Where can I find the list of electrical components for the latest version of the** ``LPA``?
| A5: The bill of materials (BOM) for electrical components is located in *LPA-hardware-x.x\\CAD Files\\Circuit Board\\Production Files* of each release. The BOM and component spreadsheets are formatted so they can be sent for commercial assembly. Note that the BOM does not include the LED sockets which should be assembled and soldered manually with the LED socket aligner.

| **Q6: A component in the bill of materials is no longer available, what should I do?**
| A6: Check if anyone has raised an `issue <https://github.com/taborlab/LPA-hardware/issues>`_ for the same part on github. If not, let us know by submitting one. When this happens the supplier often suggests a substitute or related item on the product page. If there is no obvious substitute there may be an alternative supplier.

| **Q7: Where I can find the PCB stencil file, and is there a corresponding .pdf, or .doc (or something similar) that I could open on my PC?**
| A7: PCB production files (Gerbers) are located in *LPA-hardware-x.x\\CAD Files\\Circuit Board\\Production Files*. In Gerber format, stencil files are specified by ".gtp" (gerber top paste) and ".gbp" (gerber bottom paste). Since we recommend only performing surface mount component soldering on the bottom layer, you will most likely only need the bottom stencil file. The entire PCB layout can be viewed (and modified) in KiCAD by opening the .pro file located in *LPA-hardware-x.x\\CAD Files\\Circuit board\\KiCAD Files*. You can also find free software online for opening individual gerber files.

| **Q8: How do I determine the correct indicator LED orientation?**
| A8: The most obvious feature on the indicator LEDs is a "T" shape on the back which indicates polarity. Even though all three indicator LEDs are from the same manufacturer, the graphic is not consistent in indicating polarity. For these LEDs, the bottom of the "T" feature indicates:

| Green ("on", 475-1410-1-ND): cathode (GND)
| Red ("err", 475-1415-1-ND): anode
| Yellow ("fin", 475-2560-1-ND): cathode (GND)

In ``LPA v1.0``, GND is marked by a small nub in the silkscreen. Therefore, the bottom of the "T" should point toward (green), away from (red), and toward (yellow) the silkscreen nub.

In ``LPA v1.1``, the inconsistency is taken into account, and the silkscreen nub indicates the correct side of the "T" feature. Therefore, the bottom of the "T" should point toward the silkscreen nub for all three LEDs.

| **Q9:** ``LPA v1.1`` **indicator LEDs are located on top of the circuit board, how should I solder these?**
| A9: Even if you are outsourcing the SMC soldering to a company, you will likely solder the indicator LEDs yourself since keeping assembly to one side of the board significantly reduces cost. Depending on your circumstances, there are multiple ways of doing it:

*Soldering iron method*: Choose this method if you are not set up to perform reflow soldering, or if your board has already been commercial assembled on the back and you don't want to risk messing it up. First, use tweezers to place the indicator LED (link!). Take your hot soldering iron (the smaller the tip the better) and get a small drop of solder on the very tip. While holding the indicator LED in place with tweezers, transfer the small drop of solder to one terminal of the LED. Once one terminal is even slightly soldered in place, you can solder the other terminal relatively easily. Ensure good conductance between LED terminal and pad by heating both areas with iron and re-melting the solder.

*Reflow (oven) method*: Two successive rounds of reflow soldering can be performed to get all SMCs soldered on both sides of the circuit board. There are YouTube videos demonstrating how to do it. By this method, you perform reflow soldering on one side of the board, let it cool, and then perform reflow soldering on the second side. In the second round, the board needs to be raised off the oven rack so that it's not resting on any components. As long as the SMCs which are facing down are not too heavy, surface tension will keep them in place. If you try this method, keep the back side of the circuit board facing up during the second round of reflow. This way only the LED indicators fall off in the worst case scenario.

| **Q10: I'm having trouble programming the firmware, is there a set of quick instructions I can follow?**
| A10:

1. Download/install Atmel Studio 7.0  (web installer)
2. Plug in AVRISP mkii (programmer) to computer usb (wait ~10s for computer to recognize device)
3. Power ``LPA`` and connect to programmer, programmer indicator LED should change from red to green
4. In Atmel Studio go to Tools>Device Programming. Select AVRISP mkII as tool, ATmega328 as device, ISP as interface. Press read device signature and voltage (3.3 V).
5. Click on the "Fuses" tab. Use the settings below (also found in *LPA-hardware-x.x\\Firmware\\Compiled\\fuses.txt*) and then click Program.

     For ``LPA v1.0``:

      Uncheck CKDIV8 box, check the CKOUT box, and set SUT_CKSE` to EXTXOSC_8MHZ_XX_1KCK_14CK_65MS

     For ``LPA v1.1``:

      Uncheck CKDIV8 box, check the CKOUT box, and set SUT_CKSEL to EXTXOSC_8MHZ_XX_16KCK_14CK_65MS

6. Click on the Production File tab. Click the "..." button under Program device from ELF production file. Select fimware.elf located in *LPA-hardware-x.x\\Firmware\\Compiled*.
Activate the "Flash", "Erase memory before programming", and "Verify programmed content" boxes. Click the "Program" button. Your ``LPA`` should now be programmed.

| **Q11: I cannot get my computer/Atmel Studio 7 to recognize and display my programmer, what do I do?**
| A11: Most likely, this is either an issue with the drivers on your computer (easiest thing to do is try another computer) or an incompatible programmer. We strongly recommend using an AVRISP mkII, or AVR dragon.

| **Q12: Atmel Studio recognizes my programmer, but it does not read the microcontroller or I get an error message when trying to program the device:**
| A12: There are several possible reasons to encounter this problem which all point to not having good/clean soldering job. In this order ensure that the following is true:

1. The power regulator is receiving 5 V DC and outputing 3.3 V to the microcontroller VCC pins.
2. Voltage between microcontroller VCC pins and GND pins reads 3.3 V.
3. Every pin of every component (especially the microcontroller pins) aligns and conducts with it's corresponding pad on the circuit board.
4. There are no bridged connections anywhere on the board.
5. There is no solder debris (e.g. lead flakes) causing a short anywhere on the board or on any component.

| **Q13: Once the firmware has been programmed, does the** ``LPA`` **need to be connected to a computer in order to run?**
| A13: No, once the firmware has been programmed the ``LPA`` requires no external connection other than a 5V power supply.

| **Q14: Some LEDs (possibly on large sections of the board) are not lighting up, what is causing this?**
| A14: Most likely bad soldering or bad alignment between pins on one or more LED driver and the circuit board. To solve, check for conductance between each LED driver pin and corresponding circuit board pad. If you find a bad connection, re-melt and spread around the solder on that pin/pad until you get a good connection. You may need to add additional solder (which can be tricky).

| **Q15: The circuit board component parts list calls for a quantity of 0.15 breakaway headers per ``LPA``. What does that mean?**
| A15: The breakaway headers are supplied as strips, 40 headers long, which you must manually break off to the desired length. The ``LPA`` requires two rows of three headers, for a total of six (0.15 x 40) headers.

| **Q16: Why does the** `Supplementary Information <https://media.nature.com/original/nature-assets/srep/2016/161102/srep35363/extref/srep35363-s1.pdf>`_ **state there are 7 PCB production files (6 gerber, 1 drill) when there seem to be 8 files (7 gerber, 1 drill)?**
| A16: We made a typo there. It should have stated 7 gerbers, 1 drill at that time. Luckily you cannot fabricate the board if any of those files is missing. If you're fabricating with OSHPark, you can literally just zip the production files folder and drag and drop it into their website. As of release x.xx we also include the back solder paste stencil (.gbp) file.

| **Q17: Does the microcontroller need to be programmed first in order for the LEDs to light up?**
| A17: Yes, the LEDs should not light up until the microcontroller has been programmed with the firmware.

| **Q18: What files need to be on the SD card to run the** ``LPA``?
| A18: There need to be three files: dc.txt, gcal.txt, and program.lpf. The ``LPA`` will ignore any other files on the SD card.

| **Q19: What capacity SD card do I need for the** ``LPA?``
| A19: Three files must be on the SD card to run the ``LPA``: gcal.txt (100-148 bytes), dc.txt (100-196 bytes), and program.lpf (variable). The size of program.lpf (generated by Iris) depends the length of experiment, where:

| Size (MB) = 0.3456 \* time (h), time =< 12
| Size (MB) = 0.03456 \* time (h), time > 12

| **Q20: How do I compensate LEDs across multiple ``LPAs`` to output the same intensity?**
| A20: There are multiple approaches:

* DC/GS compensation: Calibrate (link!) your LEDs to output the same intensity across multiple devices. To do this you need to measure the LED intensities across multiple devices by the same method, and then calibrate all LEDs to the single lowest LED ouput.

* Iris compensation: Compensate the IRIS intensities so that you get the same LED intensities. e.g. if you have 3 LEDs in 3 devices with max intensities 10, 5, and 2.5 umol/m^2/s, you could use IRIS intensities of 1000, 2000, 4000 to make them produce the same amount of light.

Evan Olson wrote some software for his MSB paper to automate the program generation given different LED outputs.

| **Q21: Where can I find a 1:1 scale image of the gaskets or their dimensions?**
| A21: Gasket files are contained in *LPA-hardware-x.x\\CAD Files\\Gaskets*. Individual gasket files are in .dxf format, which can be opened in many graphics editors and can easily be converted to other file formats. A complete gasket set is also provided in .ai format which meets the specifications of the laser cutting company Pololu. Gasket fabrication is described in the documentation.

| **Q22: The company assembling** ``LPA v1.1`` **for me has warned there is a mismatch between the power connector (KLDHCX-0202-A-LT) pins, which are thin and rectangular, and the PCB footprint, which consists of circular through holes. Is this actually an issue and what should I do?**
| A22: The rounded holes were made because our recommended PCB manufacturing company, OSHPark, didn't allow for non-circular holes at the time. However, soldering this component by hand is trivial. If for some reason you must have a company assemble this component, and they will not proceed with the existing design, you can modify the footprint in KiCAD to what your manufacturing company recommends. Feel free to contribute your modified design to the github repo so others may use it.

| **Q23: What is your protocol for reusing** ``LPA`` **culture plates?**
| A23: For bacteria and yeast we do the following:

1. After previous experiment, dispose cultures from wells and rinse with DI H2O
2. Submerge plate in a ~75% EtOH bath for >=30mins
3. Remove from EtOH bath, vigorously shake off residual liquid
4. Dry under flame until all liquid is evaporated (~10-15 min)
5. Dry plates can be stored by wrapping in aluminum foil.

| For mammalian cells:
| There was also a PLL coating step (see papers).

| **Q24: The power supply is not listed in the BOM, what should I use?**
| A24: The BOM only includes PCB components. The power supply should be a 5V DC switching power supply. See documentation.

| **Q25: The company assembling** ``LPA v1.0`` **for me noted that the TAB pin on the voltage regulator (LD1117S33TR) is internally connected to VOUT, but the corresponding pad on the circuit board is not routed to anything. Would you recommend keeping it this way?**
| A25: We do not know why the company pointed this out. Soldering that pin is only for structural support and heat dissipation. We do not recommend modifying the routing of that pad.

| **Q26: What LEDs should I use with the** ``LPA?``
| A26: Any standard 5 mm LED can be used with the ``LPA``. The wavelength you use depends on your optogenetic system and experiment. For examples see:

Gerhardt, et al. `An open-hardware platform for optogenetics and photobiology <https://www.nature.com/articles/srep35363>`_. *Scientific Reports* 6 (2016)

Olson, et al. `A photoconversion model for full spectral programming and multiplexing of optogenetic systems <http://msb.embopress.org/content/13/4/926>`_. Molecular Systems Biology 13(4) (2017)

| **Q27: It looks like the** ``LPA`` **LEDs are underneath the plate, but the paper mentions a top and bottom configuration.  Which is it?**
| A27: Each well has two LEDs which sit underneath the culture plate. When looking at an ``LPA`` well from a top-down perspective (as in Figure 1a of `Gerhardt et al <https://www.nature.com/articles/srep35363>`_) we refer to these as the top and bottom LED positions.

| **Q28: What shaking incubators is the** ``LPA`` **compatible with?**
| A28: Unless your shaker platform has the same hole pattern as ours (Shel Labs SI9/SI9R), you will need to modify the mounting plate (CAD Files>3D Printed Parts>LPA Parts>mounting plate) to your shaker platform specifications. Otherwise, the ``LPA`` is compatible with any shaker.

| **Q29: Do you have plans to release the** ``LPA`` **with other well formats (e.g. 12-well, 96-well)?**
| A29: Not currently. We were working on a 96-well prototype, but found it produced too much heat to be useful. Building and running multiple ``LPAs`` in parallel has worked well for us.

| **Q30: Can I use an alternative plate/well format with the** ``LPA?``
| A30: You can try, but unfortunately the ``LPA`` is designed around one specific culture plate. If you use a different plate, the wells may not align with the LEDs and the outer plate dimensions may not fit the plate adapter. You are likely to get non-uniform illumination and cross-illumination between wells. We encourage users to modify the ``LPA`` designs to their own specifications and share on github.

| **Q31: I cannot compile the firmware because I'm missing the file "SPI.cpp". Do you know where I can get this file?**
| A31: Unless you're planning on modifying the firmware, you don't need to recompile any source code. You should go through the "Firmware Programming" procedure, section 2: "Programming the device", in the SI of the `paper <https://images.nature.com/original/nature-assets/srep/2016/161102/srep35363/extref/srep35363-s1.pdf>`_. In addition, open file "fuses.txt" and set the fuses as specified there (this replaces step e. in the instructions).

If you really need to recompile the firmware, follow the instructions in the section "Firmware compiling". The procedure is rather complicated, and involves making Atmel Studio use some files from the Arduino library

| **Q32: Does the resonator (535-10008-1-ND) used in** ``LPA v1.0`` **have directionality?**
| A32: No, as long as the middle terminal gets soldered to the middle pad, the end terminals can be on either side.

| **Q33: When calibrating the LEDs with the spectrophotometer probe, were you concerned at all about getting measurements from various points throughout the well?**
| A33: For the spectrophotometer probe we used adapters to align the probe (documentation!) with either the top or bottom LED at the Z-height of the culture plate. Design files for these adapters are located in CAD Files>3D Printed Parts>auxiliary parts.

| **Q34: I'm having trouble finding the compiled firmwawre (firmware.elf) file to program the microcontroller. Where can I find it?**
| A34: The file is located in "Firmware>Compiled".

| **Q35: When using the LED socket aligner or when installing the LED spacer, it is difficult to fit the sockets into the socket holes. Do you have any good suggestions for that?**
| A35: Yes. With your existing socket aligner or LED spacer, try (1) using a pair of plyers to straighten the walls between socket holes and/or (2) use an implement such as a small flathead screwdriver to etch out any plastic debris or holes that look particularly small (3D printing is not that precise). If that fails, you may need to compensate the design files to give you the right size socket holes. However, you want the fit to be snug. The socket holes will also get looser after a few uses/installations. Also see supplementary Videos 1 and 2.

| **Q36:  The parts table for** ``LPA v1.0`` **lists a 47k ohm resistor (stated as a 50 kohm, QTY 5), but it is not listed on the LPA_BOM or LPA_Component. Is this component used?**
| A36: Those resistors were originally intended to go on the top layer of the board (empty pads in Supplementary Figure S1a) but they turn out to not be necessary. Whether or not they are soldered, they won't affect the circuit.

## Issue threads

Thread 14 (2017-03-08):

File format

RaphP, 2017-03-08:
Dear Taborlab,

we are very interested in your project, thank you very much for uploading it on GitHub !!
I personally work mostly on open source software when I can. Would it be possible to have generic 3D printed files (.STL for exemple) instead of solid works ?
We might have a solid work licence at the lab, so maybe I can have the tech guy that use it let me convert the files and then with your permission I can upload them on the git ?

Best regards,
Raphaël.

castillohair, 2017-03-08:
Hi Raphael,

Please find the .STL files [here](https://github.com/taborlab/LPA-hardware/releases/download/v1.0/lpa.zip). We keep these, as well as other ready-for-manufacturing files in the [Release](https://github.com/taborlab/LPA-hardware/releases) section.

Hope this helps,

Sebastian.

RaphP, 2017-03-08:
Dear Sebastian,

thank you very much for that !

Best regards,
Raphaël.

Closed 2017-03-08.

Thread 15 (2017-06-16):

Outsourced pcb manufacturing + assembly

cuong450, 2017-06-16:
Here are the issues mentioned by the outsourced company:

Thank you so much for your updated design, and we still have below issues:

1.#11_L1 p/n: VLS6045EX-151M does the orientation matter for this part?

[issue1_2 jpg](https://user-images.githubusercontent.com/15172848/27229032-fa494398-5277-11e7-9038-b892934466d1.jpeg)
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

2. In your new Gerber, there is no negative pole marks any more. Please comment.(We know you don't need us the solder the parts on the top side, but we just remind.)

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

KarlGerhardt, 2017-06-16:
Hi Cuong,

1. I believe inductors in general don't have polarity, but each pad of the component should be aligned and soldered with only a single pad on the PCB. This would be consistent with having the component's indicator "dot" over one pad or the other. Sebastian can you confirm?

2. The orientation does matter. It should be visible in the front silkscreen as in the below image.

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

Cheers,
Karl

castillohair, 2017-06-16:
Hi Coung,

1. As Karl said, the orientation of the inductor L1 does not matter.

2. I'm opening the gerber files directly and the polarity marks for the LEDs are there, specifically in file `lpa-F.SilkS.gto`. I used the program Gerbv version 2.6A, which is free to download. Screenshot below.

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

I'm worried that if the manufacturing company can't see certain layers for some reason, then they might miss the polarity in certain components in which it matters. Can you check with the company that they can see the polarity in capacitors C3, C5, diode D49, and component X1?

Hope this helps.

castillohair, 2017-06-20:
Cuong,

Did you ask about the polarity of the other components?

castillohair, 2017-06-25:
Closed due to inactivity.

Closed 2017-06-25.

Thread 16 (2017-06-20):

Outsourced pcb manufacturing + assembly # 2

cuong450, 2017-06-20:
Hi,
The pcbs manufacturing + assembly company has 2 more questions. Please see attached

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

Thank you for your fast replies.

castillohair, 2017-06-20:
1) Those holes don't need to be plated.

2) Yes you can trim off those texts.

Closed 2017-06-20.

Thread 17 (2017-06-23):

Power Supply

apolnaszek, 2017-06-23:
Hello, I recently started working on a copy of the LPA and was wondering what voltage power supply the PCB needs. I didn't see a power supply on the BOM.

apolnaszek, 2017-06-23:
Looking through the data sheets I think I've come to the conclusion that a 12V, 2.1mm x 5.5mm, AC/DC power supply is needed. Can anyone confirm?

KarlGerhardt, 2017-06-23:
Hello apolnaszek,
Glad to hear you are building an LPA. Definitely read through the supplemental information to the publication. Table S1 shows the parts (beyond the BOM for circuit board assembly) you will need, including the power supply. You will need a switching power supply which supplies 5V DC.

Best regards,
Karl

apolnaszek, 2017-06-23:
Thanks for the quick response, Karl. I'm new to GitHub and I've looked through the files and folders a couple times but couldn't find Table S1. Could you point it out for me?

KarlGerhardt, 2017-06-23:
Sorry, I assumed you were familiar with the publication on this hardware.
https://www.nature.com/articles/srep35363
Near the bottom you can find the supplementary information as a .pdf

apolnaszek, 2017-06-27:
I've been looking through the publication the last few days and trying to come up with a list of parts to order. I'm a little confused as to how the S1 table and BOM overlap. Some parts are on both lists and some aren't. Also, both lists have a different 16 MHz resonator crystal. Do I need both or just one?

KarlGerhardt, 2017-06-28:
The BOM only has the components for commercial assembly of the circuit board. Table S1 should have ALL necessary electrical components. However, the current release (see "Releases") has an updated circuit board (with some new/different components). These changes have been made in the BOM, but we have not released an updated Table S1 (or any updated documentation documentation for that matter).

If you want to build the new board, you will want to use the components in the BOM. Keep in mind, the BOM doesn't include the board components which we recommend soldering yourself (e.g. LED sockets), but there have been no changes to those.

castillohair, 2017-06-28:
To summarize, you will need all components specified in the BOM, plus LED sockets (48 units, PCV_220-ND on digikey) and a power supply (418-TRG1505-V on mouser).

Closed 2017-06-23.

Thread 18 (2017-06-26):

reference designators (Y1,C4) in the pick and place file

cuong450, 2017-06-26:
There are no coordinate for below reference designators (Y1,C4) in the pick and place file. Could you please help resend us the complete pick and place file?

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

KarlGerhardt, 2017-06-26:
These are components from the original design and are no longer used. The complete pick and place file is called "LPA_component.xlsx" located in the production files folder. They seem to be generating their own list based on the gerbers, which probably contains some vestigial links to old components. Sebastian can you comment?

castillohair, 2017-06-26:
I manually removed every trace of old components from the KiCAD files (they're essentially text files), which were then used to generate the gerber files. You can open file `lpa.kicad_pcb` with a text editor and search for `Y1`, and you are not gonna find it. Same with each one of the gerber files and the drill file. So I don't think this is the case. My best guess is that they just modified a component file that they started from the previous design, instead of starting from scratch as they should have.

I suggest you email them the file "LPA_component.xlsx" from the production folder in the **latest** design. If they are somehow generating the component file from the gerber files, tell them to do it from scratch.

Closed 2017-06-28.

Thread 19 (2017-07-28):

Atmel Connectivity Issue at 2.3V rather than 3.3V

cuong450, 2017-07-28:
Hi,
I am currently having issues connecting to Atmel studio, my target voltage is 2.3V rather than the instructed 3.3V.

My board was manufactured and soldered by an outsourced company. I have not manually soldered the LED sockets on, but I have manually soldered on the barrel connector, the reset switch (is this orientation specific?), the 3 ON ERR FIN indicator LEDs  ( orientation of cathodes pointing toward the ON ERR FIN etching ). Please let me know what I can do to trouble shoot the issue? Thank you.

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

castillohair, 2017-07-28:
Hello,

I have a couple of follow up questions.

- Is 2.3 the voltage according to Atmel Studio?
- What power supply are you using?
- I would need a closer look at the programming pin connectors. It is currently hard to see if the wires match the respective pins, especially the red wire.
- Is this a problem with all the boards that you received? or just that one?
- The logical next step would be to check voltages at different points in the board and isolate the problem. Do you have access to a multimeter? Do you feel confident in using it? I ask because if you're not experienced and you're not careful, you could short two board contacts with the probes and burn something.
- The last option is for you to send us the board and we can look at it here and mail it back (all mailing costs covered by you or your lab, of course).e

cuong450, 2017-08-01:
- Is 2.3 the voltage according to Atmel Studio?
yes reading is through Atmel Studio 7.0
- What power supply are you using?
5.0V
- I would need a closer look at the programming pin connectors. It is currently hard to see if the wires match the respective pins, especially the red wire.
The red wire is facing facing towards the reset button and away from SD card
- Is this a problem with all the boards that you received? or just that one?
I did not go through with the purchase of other boards, I wanted to verify that this one works before I order more
- The logical next step would be to check voltages at different points in the board and isolate the problem. Do you have access to a multimeter? Do you feel confident in using it? I ask because if you're not experienced and you're not careful, you could short two board contacts with the probes and burn something.
Do you have a diagram of the expected voltages expected at each pin of the electrical board? If so, I can do the checks. If no please set up a Skype session so we can go through this together
- The last option is for you to send us the board and we can look at it here and mail it back (all mailing costs covered by you or your lab, of course).e
I would prefer to have an understanding of where the problem lays for future references, so I want to troubleshoot this in-house before the last resort.

castillohair, 2017-08-02:
The red wire should be coming into pin #1 of the connector, which is highlighted on the board with a white dot next to it. I can see the dot in your picture, below the P2 label. In other words, pin #1 of the connector is next to the SD card connector and away from the reset button, into the board and away from the edge. Please check these connections and let me know.

What programmer are you using?

cuong450, 2017-08-02:
Yes, this may be the issue. My current programmer (Atmel-ICE) . The red line does not go to the white dot on this model's configuration, the red line goes to a middle pin, which is incorrect.

https://www.digikey.com/product-detail/en/microchip-technology/ATATMEL-ICE-BASIC/ATATMEL-ICE-BASIC-ND/4753381

A collaborator provided me with this controller because they could not purchase the obsolete AVRISP mkII programmer (https://www.digikey.com/products/en?keywords=AVRISP%20mkII%20programmer). Do you have a source provider for this obsolete item?

castillohair, 2017-08-02:
I see. Your programmer should certainly work, but it also has many more advanced programming modes that we're not using and could be causing you some confusion.

Going through the manual, it seems that the red wire should go to pin 3, which the middle pin facing the inside of the board and away from the edge, which is kind of confusing. Please make sure that this is the case. Also, make sure that you select programming mode ISP or SPI when you try to connect to the programmer via Atmel Studio.

Let me know if any of this works.

cuong450, 2017-08-02:
Yes it works. I was under the impression that the red wire should be facing away from the SD card as instructed in your manual file, but this is not applicable (but rather opposite) for the ATMEL ICE programmer. Thanks will let you know about further progress.

castillohair, 2017-08-02:
Yeah apparently the red wire position depends on the programmer. It's good that we figured this out. Please keep us in touch about your progress.

I'll close this issue now.

Closed 2017-08-02.

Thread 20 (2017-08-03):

step G of Page 51 of 78 instruction

cuong450, 2017-08-03:
g. Make sure that the “Flash”, “Erase memory before programming”, and “Verify programmed content” checkboxes are activated, and click on the “Program” button. The messages “Erasing device... OK”, “Programming Flash...OK”, and “Verifying Flash...OK” should appear below.

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

Hi, Please see the attached screen shot of errors. What do you suggest?

castillohair, 2017-08-03:
How many times did you try? Sometimes programming just fails for no reason, but then it works the next time.

castillohair, 2017-08-03:
Also, on the fuses tab, you need to select the option with "16K CK/14CK" instead of "1K CK/14CK". This change is necessary for the new board model that you're building (as opposed to the model that we published in the paper).

cuong450, 2017-08-03:
after switching to "EXTXOSC_8MHZ_XX_16KCK_14CK_65MS"., I have tried it about 20 times now. In my past, certain SD cards are rejected by certain programming chips. Can you tell me the specific SD card brand that you are using? (I am using Kingston 16GB SD)

Do you have other suggestions?

castillohair, 2017-08-03:
So switching to "EXTXOSC_8MHZ_XX_16KCK_14CK_65MS" did not change anything?

cuong450, 2017-08-03:
It just worked with  "EXTXOSC_8MHZ_XX_16KCK_14CK_65MS" setting and removed SD card. Good to know

castillohair, 2017-08-03:
Glad it worked.

cuong450, 2017-08-03:
however, the error LED is on? what does this mean?

cuong450, 2017-08-03:
I see that it says it means no SD card available, but I plugged SD card back in. and error still present.

castillohair, 2017-08-03:
Did you push the reset button after inserting the SD card?

cuong450, 2017-08-03:
Yes, but the SD card does not have anything on it at the moment.

Am I suppose to put the dc.text and gcal.text file + the downloaded program.lpf files on the SD card?
Only those specific 3 files and nothing more?

In any folder of any name?

castillohair, 2017-08-03:
Yes. Those files should be in the SD card itself, not in a folder.

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

Closed 2017-08-03.

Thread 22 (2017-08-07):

Maximal light intensity from LED source

cuong450, 2017-08-07:
Hi,
Do you have any measurements of the maximal light intensity from LED sources?

In the case that the LED source intensity is too weak, and our biological assay needs higher intensities, what do you recommend that we do? Is it true that there is a 17mA maximal drive current for each LED?

Is it possible to modify the pcbs board components so that there is more driving current for a higher intensity LED bulb?

castillohair, 2017-08-08:
Hi,

The maximum intensity depends on the specific LEDs being used. If you wanna see examples, check the following papers: https://www.nature.com/articles/srep35363?WT.feed_name=subjects_biotechnology and http://msb.embopress.org/content/13/4/926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.

Dot correction values (numbers in the dc.txt file) can increase the overall intensity of the LEDs. The maximum DC value that you can ever set is 63, though. In our experience, if you ever use dot correction values past 30 or 40, the board's temperature can increase to such levels that the cell culture will not grow appropriately. Most of our work has been performed at dot corrections lower than 10.

Closed 2017-08-08.

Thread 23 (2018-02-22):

problem with 96 well LPA

HMoerten, 2018-02-22:
Hi,

my name is Hanns-Martin &  and after reading your inspiring publication, I have successfully built the 24 well LPA. A little unusual though, since I am a molecular biologist by education, but  neither an optogeneticist nor very familiar with coding or with the details of electrotechnical circuitry. I have some experience with the development of biotechnical devices  though and was just enthusiastic about the possibility of building a small biotech device in the spirit of the DIY/ maker movement.

After building the device, I simply asked a few labs here in Germany if they were interested of testing the LPA. To make a long story short, I was asked if I could come up with a 96 well solution as well.

Since I am, as mentioned, not all too good at coding (though brave enough to change code here and there), I thought that daisychaining 12 TLC5941s would somehow be the simplest solution. After being able to programm .lpfs with the jupyter notebook  files, I found the 96well config.h you put on github and saw no reason why that should not work. On the hardware side, I constructed a breadboard circuit that mirrors the 24 well LPA, with more TLC5941 elements though.

So here comes my problem: I can get an 88 well version with 2 channels each (so 176 channels and TLC 5941_N set to 11) to work with. no problems so far, but whenever I switch to N set to 12 (and 192 channels) I get status LED errors, mainly of the "wrong SD file" type. Neither the compilation of the firmware.elf nor of the program.lpf files show errors. I tried all sorts of things, but have the impression there might be a physical barrier (buffer overflow? SPI limitations?). I have gone through the "demystifying the tlc 5940" book and found that there might be some clocking issues when daisychaining too many controllers.

So...any ideas on the subject? Any kind of help would be greatly appreciated!

Thank you from Cologne, Germany,

Hanns-Martin

castillohair, 2018-02-23:
Hi Hanns-Martin,

Good to know you're interested in our LPA! We have actually built a 96-well version in the past. See photos below:

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

However, we run into significant heating issues. It turns out that having that many LEDs and TLCs close together generates a lot of heat, which is unevenly distributed throughout the board, which in turn results in unpredictable cell growth rates and very noisy gene expression data. We tried several heat dissipation methods, including heatsinks (which you can see in the figure) and fans, but nothing worked to our satisfaction. Therefore, we never published on this.

I don't know what your firmware issues could be. I'm attaching below the code of the `config.h` file that we used for the 96-well device. It's been a while since we used it, so I can't guarantee that it will work with the latest firmware version. Remember that a `program.lpf` file for a 24-well LPA will not be recognized in a 96-well LPA, and this could give rise to a "wrong SD file" error. Also, as an electronic circuit gets faster and more complicated, board design becomes an important variable in terms of trying to aviod electromagnetic coupling. [This](http://www.analog.com/media/en/training-seminars/design-handbooks/Basic-Linear-Design/Chapter12.pdf) seems like a decent reference, although it is a little wordy. In short, a circuit with 12 TLCs might be beyond what can be achieved in a breadboard.

In summary, because of the overheating issues, I'd recommend to just stick with the 24-well version and avoid yourself some headaches.

```C
/*
 * config.h
 *
 * Created: 03/03/2014 02:29:05 PM
 *  Author: Sebastian Castillo
 */

// Global configuration variables
#define F_CPU 16000000UL

// Configuration for Tlc5941 module
#define Tlc5941_GSCLK_DDR DDRB
#define Tlc5941_GSCLK_PORT PORTB
#define Tlc5941_GSCLK_PIN PB0

#define Tlc5941_XLAT_DDR DDRB
#define Tlc5941_XLAT_PORT PORTB
#define Tlc5941_XLAT_PIN PB1

#define Tlc5941_SIN_DDR DDRD
#define Tlc5941_SIN_PORT PORTD
#define Tlc5941_SIN_PIN PD1

#define Tlc5941_MODE_DDR DDRD
#define Tlc5941_MODE_PORT PORTD
#define Tlc5941_MODE_PIN PD2

#define Tlc5941_BLANK_DDR DDRD
#define Tlc5941_BLANK_PORT PORTD
#define Tlc5941_BLANK_PIN PD3

#define Tlc5941_SCLK_DDR DDRD
#define Tlc5941_SCLK_PORT PORTD
#define Tlc5941_SCLK_PIN PD4

#define Tlc5941_TIMER 2

#define Tlc5941_USART_SPI 1

#define Tlc5941_N 12

#define Tlc5941_MANUAL_DC_FUNCS 1

#include <avr/io.h>
#include <avr/pgmspace.h>
#include "Tlc5941/Tlc5941.h"

/*static const Tlc5941_gsData_t well2channel[Tlc5941_numChannels] = {
	0, 1, 2, 3, 4, 5, 6, 7, 8, 9, 10, 11,
	12, 13, 14, 15, 16, 17, 18, 19, 20, 21, 22, 23,
	24, 25, 26, 27, 28, 29, 30, 31, 32, 33, 34, 35,
	36, 37, 38, 39, 40, 41, 42, 43, 44, 45, 46, 47,
	48, 49, 50, 51, 52, 53, 54, 55, 56, 57, 58, 59,
	60, 61, 62, 63, 64, 65, 66, 67, 68, 69, 70, 71,
	72, 73, 74, 75, 76, 77, 78, 79, 80, 81, 82, 83,
	84, 85, 86, 87, 88, 89, 90, 91, 92, 93, 94, 95,
	96, 97, 98, 99, 100, 101, 102, 103, 104, 105, 106, 107,
	108, 109, 110, 111, 112, 113, 114, 115, 116, 117, 118, 119,
	120, 121, 122, 123, 124, 125, 126, 127, 128, 129, 130, 131,
	132, 133, 134, 135, 136, 137, 138, 139, 140, 141, 142, 143,
	144, 145, 146, 147, 148, 149, 150, 151, 152, 153, 154, 155,
	156, 157, 158, 159, 160, 161, 162, 163, 164, 165, 166, 167,
	168, 169, 170, 171, 172, 173, 174, 175, 176, 177, 178, 179,
	180, 181, 182, 183, 184, 185, 186, 187, 188, 189, 190, 191};*/

static const Tlc5941_gsData_t well2channel[Tlc5941_numChannels] PROGMEM = {
	95, 94, 81, 80, 79, 78, 65, 64, 63, 62, 49, 48, 47, 46, 33, 32, 31, 30, 17, 16, 15, 14, 1, 0,
	93, 92, 83, 82, 77, 76, 67, 66, 61, 60, 51, 50, 45, 44, 35, 34, 29, 28, 19, 18, 13, 12, 3, 2,
	91, 90, 85, 84, 75, 74, 69, 68, 59, 58, 53, 52, 43, 42, 37, 36, 27, 26, 21, 20, 11, 10, 5, 4,
	89, 88, 87, 86, 73, 72, 71, 70, 57, 56, 55, 54, 41, 40, 39, 38, 25, 24, 23, 22, 9, 8, 7, 6,
	103, 102, 105, 104, 119, 118, 121, 120, 135, 134, 137, 136, 151, 150, 153, 152, 167, 166, 169, 168, 183, 182, 185, 184,
	101, 100, 107, 106, 117, 116, 123, 122, 133, 132, 139, 138, 149, 148, 155, 154, 165, 164, 171, 170, 181, 180, 187, 186,
	99, 98, 109, 108, 115, 114, 125, 124, 131, 130, 141, 140, 147, 146, 157, 156, 163, 162, 173, 172, 179, 178, 189, 188,
	97, 96, 111, 110, 113, 112, 127, 126, 129, 128, 143, 142, 145, 144, 159, 158, 161, 160, 175, 174, 177, 176, 191, 190,};

// Time step scaling
#define stepSizeScaling 1.0

```

HMoerten, 2018-02-23:
Hi Sebastian,

thank you very much for your immediate reply & the interesting information within!

I am aware of the heat problem & maybe using 12 TLCs is just too much. On the other hand, as mentioned, my technical problem is somewhere on the programming level between 11 and 12 TLCs and it s just driving me nuts. The config.h cannot be the problem since I have exactly/ principally  set them up (trying 48, 72, 88, well versions which all work fine) as the one you ve sent. As a control, I have used the one you ve sent though & get the same results  (192 channels just dont work) and simply reducing the number of channels bei 16 (and making N=11) combined with a program.lpf which also addresses 176 channels instead of 192 works absolutely fine. Crazy.

Electromagnetic coupling would be a problem I m sure, especially when all the little cables on a breadboard setup serve as antennas, I think that interference phenomena using PWM is very likely. Might be different on a well designed PCB though.

I will try a one channel version with 96 wells  (using only 6 TLCs) and in parallel maybe try using smd LEDs (losing the "switchability" of colors of course) which have their own little controllers (adafruit neopixels or the like). RGB Leds might be ok for some purposes, but definitely not for some wavelengths of course.

Thank you very much again for your help &

Kind regards

Hanns-Martin

tlnagy, 2019-03-21:
> However, we run into significant heating issues. It turns out that having that many LEDs and TLCs close together generates a lot of heat, which is unevenly distributed throughout the board, which in turn results in unpredictable cell growth rates and very noisy gene expression data. We tried several heat dissipation methods, including heatsinks (which you can see in the figure) and fans, but nothing worked to our satisfaction. Therefore, we never published on this.
>

Over what time frame did you have the heating issues? I'm interested in building a 96 well device, but I'll probably only have 4-10 LEDs on at one time for about 10 seconds so I don't expect to have any issues with heating.

Is there a way that you could share the plans for the 96-well device?

castillohair, 2019-04-05:
We observed those issues over 8h experiments with the LEDs permanently ON at different intensities. I couldn't tell if your situation will not lead to heating until after trying. Nevertheless, our 24-well LPA design v1.1 has some upgrades that are supposed to minimize heating and that I would like to incorporate and test into the 96wp design.

Do you have an email so I can send you the 96-well design files?

tlnagy, 2019-04-05:
> Nevertheless, our 24-well LPA design v1.1 has some upgrades that are supposed to minimize heating and that I would like to incorporate and test into the 96wp design.

Great!

> Do you have an email so I can send you the 96-well design files?

My email is in my Github profile. Thanks!

castillohair, 2019-04-08:
No problem! I'm not in lab today, so I will send you the files tomorrow morning.

Closed 2018-04-04.

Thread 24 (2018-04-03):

Outsourced Soldering questions

cuong450, 2018-04-03:
Hi,
I have 2 questions about soldering via a pick and place method. #18 refers to the item #18 in the BOM attached.

1. #18_P2 p/n: 9-146282-0 this is a 40 pos single row connector, yet P2 is  a double row 2*3pos footprint, so we need to cut them into 3 pos, then solder 2 single rows on the P2 footprint, right?

2. #19_CON1 p/n: KLDHCX-0202-A-LT the part has 3 slots(physical dimensions are: 0.5*3.0mm, 0.3*2.2mm and 0.3*2.5mm), while in the Gerber they are all 3.0mm holes.
Due to the thin pins, it will be better to use slot design, because too large hole may easily cause solder leak to the opposite side.
So please help change the holes into slots and considering the production tolerance, please use dimensions for pin1:0.6*3.2mm, and for pin2:0.4*2.7mm, and for pin3: 0.6*2.4mm.
Thank you.
[LPA_BOM.xlsx](https://github.com/taborlab/LPA-hardware/files/1872931/LPA_BOM.xlsx)
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

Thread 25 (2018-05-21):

SD card socket

kleagsand, 2018-05-21:
I'm trying to order all these pieces from DigiKey but the SD card socket is obsolete, is there a different part number I can replace this with?

Thanks in advance

Keagan

castillohair, 2018-05-23:
It seems like this one has the same soldering pad layout and could therefore work as a replacement: https://www.digikey.com/product-detail/en/amphenol-fci/10067847-001RLF/609-3956-2-ND/2283478

Closed 2018-07-12.

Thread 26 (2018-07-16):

Gerber file for stencil not included in production files

KarlGerhardt, 2018-07-16:
Solder paste stencil is specified by the .gbp (gerber back paste) and .gtp (gerber top paste). We never included these files in the circuit board production files.

Up to this point users likely either:
1. Generated the .gbp from lpa.pro using KiCAD (probably technical users only)
2. Fabricated the stencil using the .gbs (soldermask, includes drill holes --> problems)
3. Provided stencil company with all the gerbers in the production files from which a correct stencil could be generated.
4. Performed commercial assembly

Repo should be updated to include the .gbp, and possibly issue a new release.

KarlGerhardt, 2018-09-19:
Made a Youtube tutorial for stencil generation in the meantime. https://youtu.be/N_PYzLDjrIM

Closed 2019-08-09.

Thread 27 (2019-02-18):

12pF Capacitor

phuongho43, 2019-02-18:
Seems like the listed 12pF capacitor is out of stock:
https://www.digikey.com/product-detail/en/samsung-electro-mechanics/CL21C120FBANNNC/1276-2579-1-ND/3890665

Would this one work?
https://www.digikey.com/product-detail/en/samsung-electro-mechanics/CL10C120FB8NNNC/1276-2175-1-ND/3890261

KarlGerhardt, 2019-02-18:
I don't think the replacement you suggested will work since the package size is different (2.00mm x 1.25mm vs. 1.60mm x 0.80mm).

This one ([720-1704-1-ND](https://www.digikey.com/product-detail/en/vishay-vitramon/VJ0805A120GXAPW1BC/720-1704-1-ND/8324124)) will probably work. The only difference I see is the tolerance is a little bit higher at 2%.

Look good to you Sebastian?

castillohair, 2019-03-04:
Sorry for the delay. I've been out of commission as @KarlGerhardt knows.

Are these the capacitors for the crystal circuit? If that's the case, @KarlGerhardt 's choice is probably good. However, I would prefer to maintain the tolerance for such a sensitive portion of the design. This could be a better replacement: https://www.mouser.com/ProductDetail/AVX/08055U120FAT2A?qs=sGAEpiMZZMs0AnBnWHyRQKdiqyDPVQdAQn0ajLazkVM%3D. But I must say that I know very little about crystal oscillators, and it would take me a non-trivial amount of time to figure out whether the 1% increased tolerance matters or not. But worst case scenario, I think the timing error will shift by no more than a few seconds for an 8-hour program.

tldr; @phuongho43 if you're already bought @KarlGerhardt 's suggestion, don't worry and carry on. But if not, I would recommend to buy the one I suggested instead.

castillohair, 2019-03-07:
I opened a new issue (#28) to remind us to change the capacitors in the parts list.

I will now close this issue. @phuongho43 feel free to reopen it if you have further questions.

Closed 2019-03-07.

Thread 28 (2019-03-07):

Replace oscillator capacitors in parts list

castillohair, 2019-03-07:
See #27.

The following capacitor is no longer in stock at digikey: https://www.digikey.com/product-detail/en/samsung-electro-mechanics/CL21C120FBANNNC/1276-2579-1-ND/3890665

This might be a suitable replacement: https://www.mouser.com/ProductDetail/AVX/08055U120FAT2A?qs=sGAEpiMZZMs0AnBnWHyRQKdiqyDPVQdAQn0ajLazkVM%3D

Closed 2019-07-08.

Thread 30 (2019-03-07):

Replace included cytometry tube rack

castillohair, 2019-03-07:
Do we want to replace the cytometry tube racks included with the ones Evan used in his thesis? It seems that every time somebody has built new racks in our lab in the last few years, it has been Evan's design and not the ones in this repo.

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

The only minor inconvenient is that these have not been designed in SolidWorks, so they would stick out with respect to the other 3D printed parts in this repo. But I don't think this should get in the way of presenting improved parts.

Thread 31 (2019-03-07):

Remove stepSizeScaling from firmware code

castillohair, 2019-03-07:
Time step calibration is not necessary with the LPA board design v1.1. The firmware still has code to allow performing time step calibration, though. I think this should be erased.

castillohair, 2019-03-07:
To expand on this, the only use case I can think of where deleting this section would be problematic is if a user downloads the most recent firmware and tries to program an LPA v1.0 board.

This begs the more general question, should the firmware, at any time, be compatible with every previous LPA PCB version? I think the answer is no, because this restriction could make the firmware really hard to update and maintain. Thus, what a user with an LPA v1.0 board should do is to download the LPA v1.0 firmware. And we should make that very clear and easy to do.

@KarlGerhardt if you have opinions on this let me know.

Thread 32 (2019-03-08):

SD card not recognized by LPA

GolgiWhillikers, 2019-03-08:
I am building an LPA v1.1. I have been unable to get the board to recognize the SD card (stable ERR light). On very rare occasions, I will instead get the flashing ERR light instead, but maybe 1 out of 30 times. Used Atmel studio and an AVRISP XPII to program and everything seemed to go fine (no errors). The only difference I saw was that it recognized the power source as 3.1V rather than 3.3V. I have tried programming simple and dynamic programs in Iris, and moving the lpf file to the SD card along with the stock gcal.txt and dc.txt files from the firmware master folder. Usually, after plugging in the power, the LEDs on the board all flash very briefly, then turn off, and the ERR light remains on. Changing the order of events of plugging it in, inserting SD card, etc has not changed the behavior, nor has pressing the reset button (ERR light turns off with push then back on after release).

I am using an alphx innovations 2GB SD memory card, and have tried formatting it in FAT, FAT32, exFAT, and NFTS with no changes. Is there an SD compatibility issue here? We also tried a more current microSD card (in an adapter) with no luck. The SD reader on the board is the replacement one defined in issue #25.

Thanks for your help.

castillohair, 2019-03-08:
Hi @GolgiWhillikers ,

Just to be sure, the appropriate order of events should be either:
- Insert SD Card
- Plug the power connector

or
- Plug power connector
- Insert SD card
- Press reset button

Is this what you're doing?

Also, did you program the firmware AND fuses of the microcontroller? The full procedure is described here: http://taborlab.github.io/LPA-hardware/initializing/firmware/firmware_programming.html. However, in step e) you should select `EXTXOSC_8MHZ_XX_16KCK_14CK_65MS` instead of `EXTXOSC_8MHZ_XX_1KCK_14CK_65MS` if you have built an LPA v1.1. We currently have a fair amount of the documentation in http://taborlab.github.io/LPA-hardware describing the previous LPAv1.0, but we're in the process of updating it.

The 3.1V measurement worries me a little. If you have access to a multimeter, it would be great if you could use it to double check the voltage in the board.

If all of these are correct and the SD card is still not being recognized, my best guess is that there is a soldering issue somewhere. @KarlGerhardt and I could help you debug this, but it would be better to first rule out the things I described above.

GolgiWhillikers, 2019-03-13:
Well, I seem to have resolved the issue, but I'm not 100% sure what the fix was. I think the most likely scenario is I was trying to load bad Iris programs onto the LPA (the learning curve was steeper than I expected)--I noticed if I plug the SD card in with no lpf program on it, I get the same error light as before. But now, with the SD card formatted in FAT (which is what it was set to by default), with the dc, gcal, and lpf files on the card, it works perfectly fine. Tested 4 SD cards from the same manufacturer and they all worked. I did double check all the flash settings, but we never re-flashed the microcontroller and now it works. So, thanks for the response, seems like everything is good now!

phuongho43, 2019-03-24:
Did the format of the SD card matter (would it still work with NTFS or exFAT)? Also, are the dc and gcal files in the "Image analysis script" folder? I don't see them in the firmware folder. Can example dc, gcal, program.lpf files be included in the repo?

GolgiWhillikers, 2019-03-24:
I don't 100% understand why it worked after not working for me. The SD card was formatted as FAT (which was the default formatting). There is an example dc and gcal.txt file in the Image analysis folder in the repo which is what I have been using to test my files.

I suspect my problem was that I had not programmed a valid file in Iris, so it didn't work. It would have been useful to have a demo lpf file available for that reason.

castillohair, 2019-03-24:
Hi @GolgiWhillikers  and @phuongho43,

SD cards should be formatted in FAT (aka FAT16) or FAT32, but FAT is preferable. NTFS or exFAT are not supported.

@KarlGerhardt and I are pretty busy for the next couple of weeks, but after that we will release a new version with better file organization and updated documentation. We will make sure to have a set of example files in a more obvious location. For now, you can use dc.txt and gcal.txt from the image analysis folder, and generate a program.lpf file from [Iris](http://iris.taborlab.rice.edu).

phuongho43, 2019-03-25:
It worked! :)
The format was the issue after all. The SD card I got is 64GB and apparently FAT16 has a 4GB limit so I had to make a small enough partition using disk management (Windows 10).

Closed 2019-03-13.

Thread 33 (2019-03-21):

Control LPA via SPI

tlnagy, 2019-03-21:
This is an awesome little board, but my purposes I would love to be able to send signals to the board via serial command. I plan to use the device on a microscope and it would greatly help synchronization if the computer could send a signal that could tell which LED to turn on for how long.

My plan was use an Arduino to send SPI commands to the LPA over the 2x3 SPI pins on the LPA and rewrite the firmware of the LPA to interpret those signals and only turn on the wells that are needed and for the given length of time.

Do you all think this is reasonable? I'm worried that since SPI is already used to control the TLC chips/LEDs that this might not work. I would appreciate your all's thoughts as I'm pretty new to microcontrollers.

castillohair, 2019-04-05:
Hello!

Sorry for the late response. Both Karl and I are deep into thesis defense business these days.

If I'm understanding correctly, you want to use an Arduino to send SPI commands to a free SPI input in the LPA, and rewrite the firmware to use these values to update the LEDs. I think this is feasible. The SD card socket currently uses the SPI module (the LED drivers use the USART module in SPI mode). So you could remove SD card functionality from the firmware and use the now free SPI module for your purposes. The only caveat is that the Slave Select (SS) pin from the SD card module is not available through the 3x2 connector. I think you could get away with soldering a wire from the mircontroller's SS pin to ground, but I would have to look at the datasheet in more detail to be 100% sure.

The other option, if you are willing to do some electronic board redesign, is change the SPI module to manage the LED drivers and use the USART module to communicate directly with the PC without an arduino. This would require rewiring the microcontroller pins and adding a serial connector while removing the SD card connector. This may be a more robust solution depending on how many of these you want to make, how much space you have, and how robust you want it to be.

Let us know if you have any more questions. I will try to reply much faster this time.

tlnagy, 2019-04-05:
> If I'm understanding correctly, you want to use an Arduino to send SPI commands to a free SPI input in the LPA, and rewrite the firmware to use these values to update the LEDs.

This is correct.

> The other option, if you are willing to do some electronic board redesign, is change the SPI module to manage the LED drivers and use the USART module to communicate directly with the PC without an arduino. This would require rewiring the microcontroller pins and adding a serial connector while removing the SD card connector.

This sounds like the approach I would take. What software would you recommend for designing PCBs? I was planning to use Fritzing.

castillohair, 2019-04-08:
I would recommend KiCAD, which is what we used. With it, you should be able to start from our files which should reduce the amount of work you have to do.

Good luck! Please let us know if you have any more questions. And if you're successful, it would be great to have your design available as a fork of our project so that other people with similar needs can use it.

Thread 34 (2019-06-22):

Long Runtime error - Intensity of Lights Change Over Time on Steady State Program

ramininaieni, 2019-06-22:
A long time (~20-30 minutes) after a Steady State Iris program starts to run, the LEDs on our LPA device begin to change in intensity over time. The indicator LEDs on our device throw almost all of the error signals after a long time running the program correctly and flashing green indicating so. The indicator LEDs have thrown error lights indicating "this device has not been able to maintain the specified resolution - ON blinking, FIN off, ERR blinking" & other errors such as "no SD card - ERR on". It would be super helpful if you could let us know if this is an error you have encountered, or if you have any idea what might be causing this error. Thank you!

castillohair, 2019-06-22:
Hello,

How dramatic are the intensity changes? Are they large enough to be visible by eye? We have never seen something like what you're describing. I would first check for proper soldering of all pads. If you have a small microscope or amplifying lens, you could use it to spot any places where there is not enough solder or two adjacent pins are incorrectly connected. If all soldering is correct, I would try replacing the microcontroller or the voltage regulator chip.

ramininaieni, 2019-06-24:
Hi there,
Thank you so much for your prompt response! Yes, the changes are very visible by eye. It must be a problem with the soldering or the parts on the board if you guys haven't seen this problem before. I will let you know if this fixes the problem! Thank you!
-Roya

ramininaieni, 2019-08-08:
Hi there,
Soldering a new board with a microscope and with new parts appears to have fixed the problem! Thank you so much for your advice & help!
Sincerely,
Roya

Closed 2019-08-08.

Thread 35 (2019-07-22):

Other potential 24 well TC treated plates to use with LPA?

ramininaieni, 2019-07-22:
Hi there!

I am wondering if there are alternative vendors to get plates like https://arcticwhiteusa.com/product/awls-303008 (TC version: AWLS-303012) for use with the LPA. I am asking because Arctic White does not appear to be a conventional vendor and my lab is used to buying plates from certain vendors like VWR/Fisher/Corning. Are they the only vendors that sell plates that can be used with the LPA? Thank you!!

Best,
Roya

castillohair, 2019-07-23:
I have recently searched for cheaper equivalent plates, but to my frustration the only thing I was able to find was equivalent plates sold by other vendors. This seems to be one example https://www.thomassci.com/Laboratory-Supplies/Plates/_/24-Well-Krystal-Clear-Bottom-Polystyrene-Assay-Plates. The part number is exactly the same, as is the price if I'm not mistaken. I recommend you to request the dimensions and compare them to the ones from Arctic White before ordering. Other vendors can be found by googling "24-well Krystal™ Clear Bottom Polystyrene Assay Plates".

ramininaieni, 2019-07-24:
[page 28 of the Porvair catalog.pdf](https://github.com/taborlab/LPA-hardware/files/3428777/page.28.of.the.Porvair.catalog.pdf)

I reached out to Thomas Sci and they said that they were the same plates as the ones sold by Arctic White. To make sure, I checked the dimensions (attached above) against those of the plates used for the LPA to make sure and the plates sold by Thomas Sci do appear to be the same ones sold by Arctic White and used for the LPA. Thanks so much for all your help! I really appreciate it!

Closed 2019-07-24.

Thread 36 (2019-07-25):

How was such a low initial coefficient of variation of 7.78% achieved in LED Calibration?

ramininaieni, 2019-07-25:
Hi there!
So, for some reason my initial coefficient of variation (sd/mean) when calibrating my LEDs to each other on my board is 40%. After 3 rounds, it is reduced to 4%. This is regarding the gel imager method for single wavelength lights. I am using the same blue LEDs as those used by the Tabor lab in https://www.nature.com/articles/srep35363 (*RL5-B2545; ID: 470-SB*)

I notice that in the example provided: http://taborlab.github.io/LPA-hardware/initializing/calibration_led.html the initial coefficient of variation is 7.78% and is reduced to .55%. I also notice that in the matlab analysis, red (channel 1) and green (channel 2) are used.

In the example linked above that you provided, are you using red/green LEDs? Have you noticed a lot of/more variation in the blue LEDs that you use than the red ones?

I'm just trying to figure out why there is so much initial variation in my LEDs compared to the example and I am wondering if this is because the example is for a different wavelength LED and maybe the blue LEDs used in your research paper just have a lot/more initial variation.

Thank you soooo much for all of your help. We are really excited to start using the LPA :D

Best,
Roya

castillohair, 2019-07-29:
Hi Roya,

Sorry for the delay. I was out at a conference.

Maybe @KarlGerhardt can give you more specific answers, but I would not try to read too much on the initial variance of LED brightness. LED variance is dependent on several factors:
- intra-batch variability: if you buy 10 LEDs, they're obviously not going to have the exact emission features. And probably some manufacturers are more consistent than others.
- inter-batch variability: if you buy several batches of LEDs over a long period of time, they're probably gonna have even more different emission characteristics.
- usage: we have found noticeable degradation in light intensity in LEDs that have been heavily used. You will see even greater variability if you're combining old with new LEDs, or old LEDs that have been used unevenly.

Therefore, my recommendation is to not stress too much about initial LED variability, and just try to bring it down as much as you can. A few percentage points seems acceptable in my opinion.

ramininaieni, 2019-08-08:
Hi there,
Thank you so much for your advice. We've decided that a few percentage points (CV of 4%) is okay for our needs.
Sincerely,
Roya Amini-Naieni

KarlGerhardt, 2019-08-09:
Hi Roya,

40% seems pretty high. It's been a while since I calibrated those LEDs, but I vaguely remember them having lots of "structure" (spatial non-uniformity) in the light output. For LEDs with lots of structure, using diffuser paper is crucial.

You also want to make sure that you are not using low Iris or gcal values (e.g. < 100) when performing the calibration. I wouldn't predict this to cause high initial CV, but it can limit how low you can get the CV by calibrating.

Also, check out the recent MIE chapter [MIE chapter](https://www.sciencedirect.com/science/article/pii/S0076687919301338) which has detailed protocols.

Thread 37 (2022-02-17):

Programming issues

morphogenetic2, 2022-02-17:
Hi there, firstly many thanks for making this fully open source. I just built a LPA following your instructions and I must say that my experience with electronics is very limited. I soldered the components manually (I don't have access to an oven) and double checked every component and location and seems fine, but when I try to program it, I'm getting a low voltage warning and the programmer is not recongnizing the ATMEGA. I just wanted to know if, besides the LEDs, electrolytic capacitors and obviously the chip/LED drivers/voltage regulator, schottky diode and Xtal, if there is any other component with requires an specific polarity, like the inductor or the ceramic capacitors.

When I plug in the power supply (5V, positive barrel), is any of the SMD LEDs supposed to light up? Is there any specific connection order to program the microcontroller? Should LEDs be already plugged in in the sockets?

Sorry for many questions, but I don't have enough expertise to troubleshoot this myself, many thanks for your time.

castillohair, 2022-02-17:
Hi. Just to confirm a few things: Are you using the 1.0 design (the one with the molex connector as in figure 1 of https://www.nature.com/articles/srep35363) or the 1.1 design (the one with the barrel jack connector as in figure 2 of https://www.sciencedirect.com/science/article/abs/pii/S0076687919301338)? When you get a "low voltage" warning, does it show a voltage number? What power supply are you using? If you're using the 1.1 design, can you make sure the breakaway headers are soldered in the correct orientation (i.e. pointing in the same direction as the LED sockets, see figure 2 of https://www.sciencedirect.com/science/article/abs/pii/S0076687919301338)?.

If you have access to a multimeter, the next step would be to measure a few nodes to make sure all the voltages are correct. Also let me know if you have access to an oscilloscope. If you have access to a simple microscope, it might also be a good idea to check the soldering junctions with it. We have found false contacts or crossed junctions in other people's devices previously that weren't obvious by eye.

morphogenetic2, 2022-02-18:
Hi @castillohair thanks for the quick reply. I'm using the 1.1 design. The warning I get is that the voltage is low (0.2 or 0.3V) and that the Atmel studio is unable to recognize the device. I'm using a 5V, 2.5A, 12.5W adapter (RS online UK, P/N 175-3302), with a standard 2 mm barrel adapter (internal positive and external negative polarity). The headers are soldered in the correct orientation.

I do have access to a microscope, a multimeter and an oscilloscope. I soldered all the parts using the microscope but I'm concerned about "frying" some components due to using excessive heating, is that possible?

What nodes should I check?

Thanks very much again.

castillohair, 2022-02-18:
Good. We should start by making sure the ICs are receiving appropriate voltages. Please measure DC voltage with the multimeter between pins 1 and 4 of the AP1509 power regulator, and also between pins 3 and 4. This should be done with the power supply connected. The first one should be 5V, and the second should be 3.3V.  Be very careful to not short adjacent pins with the multimeter probes. If these measurements are successful, next I would measure voltage between pins 4 and 5 of the ATMega, which should also be 3.3V.

For further reference, I think the most up-to-date circuit diagrams of v1.1 are in my thesis https://scholarship.rice.edu/handle/1911/106008, starting from page 23.

morphogenetic2, 2022-02-23:
Hi @castillohair, I measured the voltages with a multimeter and were 5V for the jack barrel (power supply OK I guess) but zero on the voltage regulator and the IC. So I went again to check the soldering and looked clean, so finally decided to swap the voltage regulator with another one I had around, and this time worked like a charm, the voltages were correct and managed to program the ATMega with your provided firmware. Thanks so much for your support :)

castillohair, 2022-02-24:
Glad it worked out!

Closed 2022-02-24.

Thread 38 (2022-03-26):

Microcontoller availability

lanmasterlan, 2022-03-26:
Hello,

The availability of the ATMEGA328-AU is currently very bad. Can an ATMEGA328P-AU be used instead? If so, are there any firmware-related changes required?

Thank you.

castillohair, 2022-03-27:
Hi,

Thanks for your question. Unfortunately I can't 100% guarantee that they're interchangeable within the design of the LPA because I haven't tested it myself. However, from a quick search, it seems that the 328P would work fine in place of the 328. You might need to recompile the firmware though, while selecting the appropriate chip. You can check the paper's SI for more info on how to do this. If you have issues while doing this, please let us know and we can go from there.

Hope this helps.

lanmasterlan, 2022-03-29:
Thank you very much for your help.
I managed to recompile the firmware. I used the most recent version of Microchip Studio and generated libcore.a using the old Arduino IDE version 1.6.5. I adjusted the licore.a path and then changed ATmega328 to ATmega328P under Project --> Properties --> Device. I was then able to run Rebuild Solution and got the firmware.elf file, however with the warnings attached below.

Will it be okay?

Severity | Code | Description | Project | File | Line
-- | -- | -- | -- | -- | --
Warning |   | unused variable 'n' [-Wunused-variable] | firmware | C:\Program Files (x86)\Arduino\libraries\SD\src\utility\Sd2Card.cpp | 379
Warning |   | logical not is only applied to the left hand side of comparison [-Wlogical-not-parentheses] | firmware | C:\Users\user\Downloads\LPA-hardware-1.11\Firmware\Source\firmware.cpp | 42
Message |   | in expansion of macro 'System_IsState' | firmware | C:\Users\user\Downloads\LPA-hardware-1.11\Firmware\Source\firmware.cpp | 400

castillohair, 2022-03-29:
Great! I don't think those messages would be an issue.

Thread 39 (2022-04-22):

Abnormal behavior after programming

ri-zhou, 2022-04-22:
Hi,

I am unable to get the LPA to function properly after programming and I am unsure what the source of the issue is. I am an undergraduate with little electronics experience so troubleshooting has been difficult. I have consulted with some professors and graduate students and have still been unable to resolve the issue. I will try to describe the issue here.

The 48 LEDs do not light up at all. I am unable to determine the error based on the 3 indicator LEDs because all 3 indicator LEDs are turned on, which is not an error listed in the supplemental material. Additionally, the indicator LEDs occasionally will behave erratically (all three will blink, some combination will light up unexpectedly, etc.). The one condition in which the indicator LEDs behave properly is when the SD card is removed, though the board takes a while to respond.

I have checked the hardware and all connections appear to be okay. However, when I program the device, there are two areas of concern.

1. The target voltage I am reading is 4.7 V instead of the 3.3 V that should be expected based on the programming instructions. What does target voltage refer to? We are using an AVRISP 2.0. The board is powered by a 5.2 V power source. The Vout of the voltage regulator is around 3.15 V, and this goes to the Vcc of the microcontroller. I have just seen the previous issue opened on github about target voltage and will also check the orientation of my programmer (maybe the red line does not face out with this programmer).
2. When I program the chip, it says that programming flash is okay. Afterwards, it says verifying flash...failed. What might be the source of this error?

Thank you for your time and help. I believe we are using an LPA 1.0. Please let me know if there is any other information or images I can provide.

castillohair, 2022-04-22:
Hello,

If you have measured 3.15V coming out of the regulator but the AVRISP 2.0 is detecting 4.7V, it sounds like the problem might be the AVRISP or the connections to it. Note that the orientation of the programming pins are different in the LPA v 1.0 compared to v1.1. If you could send us a picture of how you soldered these pins and how you are connecting the AVRISP to it, that would be very helpful.

Thanks.

ri-zhou, 2022-04-22:
Here are some images.

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

What is target voltage? How does target voltage affect programming?

There are a few more things I want to note.
1. The programmer we are using: https://wiki.seeedstudio.com/Atmel_AVRISP_STK500_USB_ISP_Programmer/. This programmer does not list the ATMEGA328 in compatible chips, though it lists the ATMEGA328P which seems to be essentially the same thing.
2. Our AC to DC adapter outputs 5.2 V instead of 5, even though it was advertised as a 5V adapter. I do not think this is an issue, but if it is, let us know.

By the way, the second issue I mentioned in the original post (verifying flash...failed) was resolved when I changed the CKSEL to 16K CK/14CK from 1K CK/14CK, even though I am using an LPA v1.0.

Thank you for the quick response! Unfortunately, I think there is also a hardware issue as we may have damaged the voltage regulator. The measurement of 3.15 V we made was not typical. It seems that now the Vout of the regulator is typically around 2.6 V, which is an issue because the LED driver requires Vcc of 3.0 to 5.5 V. Still let me know what you think about the programmer, target voltage, and the indicator LED behavior, but it will be a few days before we can acquire a new voltage regulator and try to see if that resolves any issues.

castillohair, 2022-04-28:
Hi,

Sorry for the delayed response. You are right that 2.6V will not be enough to power the microcontroller. Did you get to replace the regulator? 5.2V at the input is fine. The only hard voltage requirement is 3.3V for the microcontroller and LED drivers, but the regulator normally takes care of that.

Also, are you programming the firmware with the SD card inside? The SD card and the programming pins come from the same place in the microcontroller, so there might be some interference there. I recommend trying to program the firmware with no SD card inserted into the board.

I would think the programmer would be compatible with all variations of the ATMega328 but I can't be 100% sure since I haven't used that particular one. I'm also not 100% sure about the SUT_CKSEL flag but after a quick inspection of the datasheet it seems to me like it would be fine.

Hopefully some of this helps. Please keep us updated!

ri-zhou, 2022-05-02:
The voltage regulator was replaced and it functions as expected now. I have not connected the programmer again and tried to read the target voltage (though it may have changed to 3.3V as expected). Thank you for your time helping with this. The voltage regulator was replaced and it functions as expected now. We appreciate your responsiveness and we hope to use the LPA soon.

Closed 2022-05-02.

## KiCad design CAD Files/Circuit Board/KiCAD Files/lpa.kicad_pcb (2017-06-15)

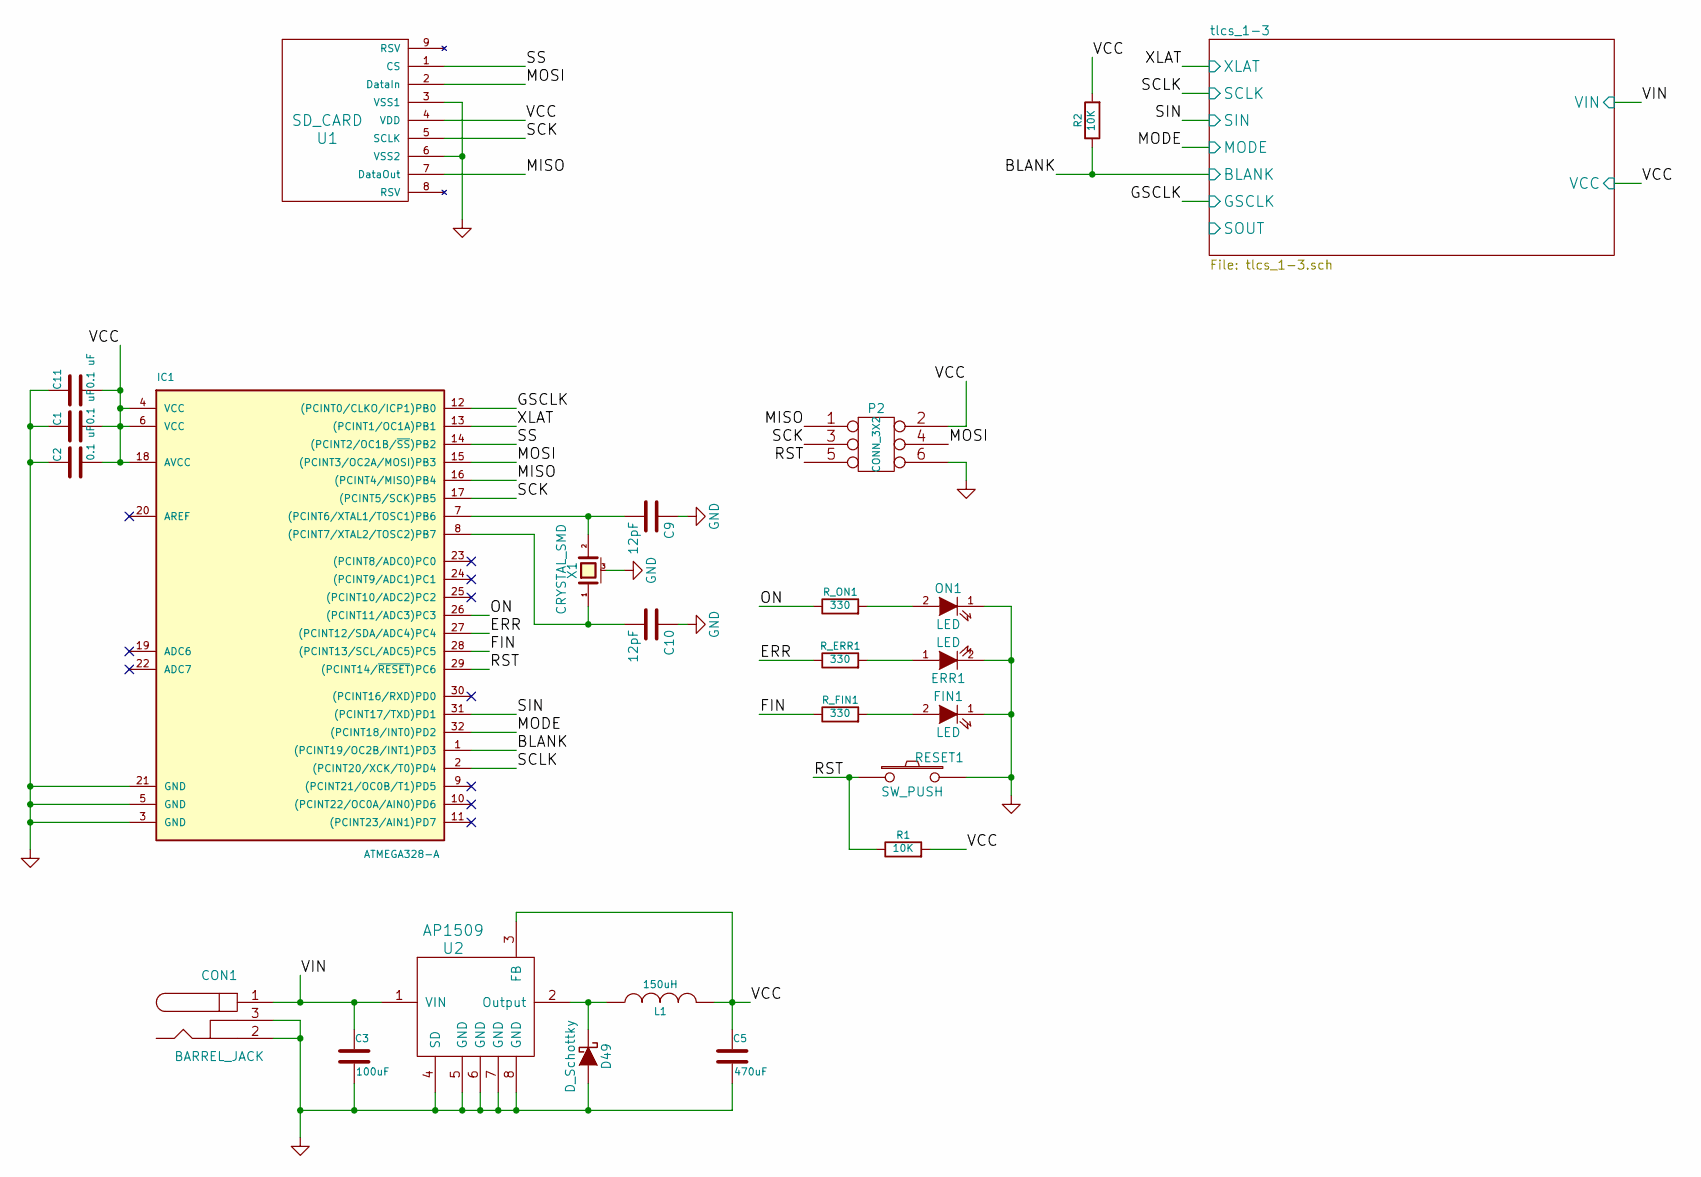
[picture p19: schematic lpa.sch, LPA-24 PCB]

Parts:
C1, C2, C11: 0.1 uF; SM0805
C3: 100uF; c_elec_6.3x7.7
C5: 470uF; c_elec_8x10
C9, C10: 12pF; SM0805
CON1: BARREL_JACK; BARREL_JACK_CIRCULAR_PADS
D49: D_Schottky; SOD-123
ERR1: LED; SM0805
FIN1: LED; SM0805
IC1: ATMEGA328-A; ATMEGA328
L1: 150uH; Inductor
ON1: LED; SM0805
P2: CONN_3X2; pin_array_3x2
R1, R2: 10K; SM0805
RESET1: SW_PUSH; SW_SPST_PTS645
R_ERR1: 330; SM0805
R_FIN1: 330; SM0805
R_ON1: 330; SM0805
U1: SD_CARD; SD_CARD_SOCKET
U2: AP1509; SOIC-8_3.9x4.9mm_Pitch1.27mm
X1: CRYSTAL_SMD; CRYSTAL_SMD_3.2_2.5_4pins

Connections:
/ERR: IC1.27 ((PCINT12/SDA/ADC4)PC4), R_ERR1.1
/FIN: IC1.28 ((PCINT13/SCL/ADC5)PC5), R_FIN1.1
/MISO: IC1.16 ((PCINT4/MISO)PB4), P2.1, U1.7 (DataOut)
/MOSI: IC1.15 ((PCINT3/OC2A/MOSI)PB3), P2.4, U1.2 (DataIn)
/ON: IC1.26 ((PCINT11/ADC3)PC3), R_ON1.1
/RST: IC1.29 ((PCINT14/~RESET~)PC6), P2.5, R1.1, RESET1.1
/SCK: IC1.17 ((PCINT5/SCK)PB5), P2.3, U1.5 (SCLK)
/SS: IC1.14 ((PCINT2/OC1B/~SS~)PB2), U1.1 (CS)
/tlcs_1-3/BLANK: IC1.1 ((PCINT19/OC2B/INT1)PD3), R2.1; also elsewhere on the board
/tlcs_1-3/GSCLK: IC1.12 ((PCINT0/CLKO/ICP1)PB0); also elsewhere on the board
/tlcs_1-3/MODE: IC1.32 ((PCINT18/INT0)PD2); also elsewhere on the board
/tlcs_1-3/SCLK: IC1.2 ((PCINT20/XCK/T0)PD4); also elsewhere on the board
/tlcs_1-3/SIN: IC1.31 ((PCINT17/TXD)PD1); also elsewhere on the board
/tlcs_1-3/VCC: C1.2, C2.2, C5.1, C11.2, IC1.4 (VCC), IC1.6 (VCC), IC1.18 (AVCC), L1.2, P2.2, R1.2, R2.2, U1.4 (VDD), U2.3 (FB); also elsewhere on the board
/tlcs_1-3/VIN: C3.1, CON1.1, U2.1 (VIN); also elsewhere on the board
/tlcs_1-3/XLAT: IC1.13 ((PCINT1/OC1A)PB1); also elsewhere on the board
GND: C1.1, C2.1, C3.2, C5.2, C9.1, C10.1, C11.1, CON1.2, CON1.3, D49.2 (A), ERR1.2 (K), FIN1.1 (K), IC1.3 (GND), IC1.5 (GND), IC1.21 (GND), ON1.1 (K), P2.6, RESET1.2, U1.3 (VSS1), U1.6 (VSS2), U2.4 (SD), U2.5 (GND), U2.6 (GND), U2.7 (GND), U2.8 (GND), X1.3 (case); also elsewhere on the board
unnamed: C9.2, IC1.7 ((PCINT6/XTAL1/TOSC1)PB6), X1.2
unnamed: C10.2, IC1.8 ((PCINT7/XTAL2/TOSC2)PB7), X1.1
unnamed: D49.1 (K), L1.1, U2.2 (Output)
unnamed: ERR1.1 (A), R_ERR1.2
unnamed: FIN1.2 (A), R_FIN1.2
unnamed: ON1.2 (A), R_ON1.2

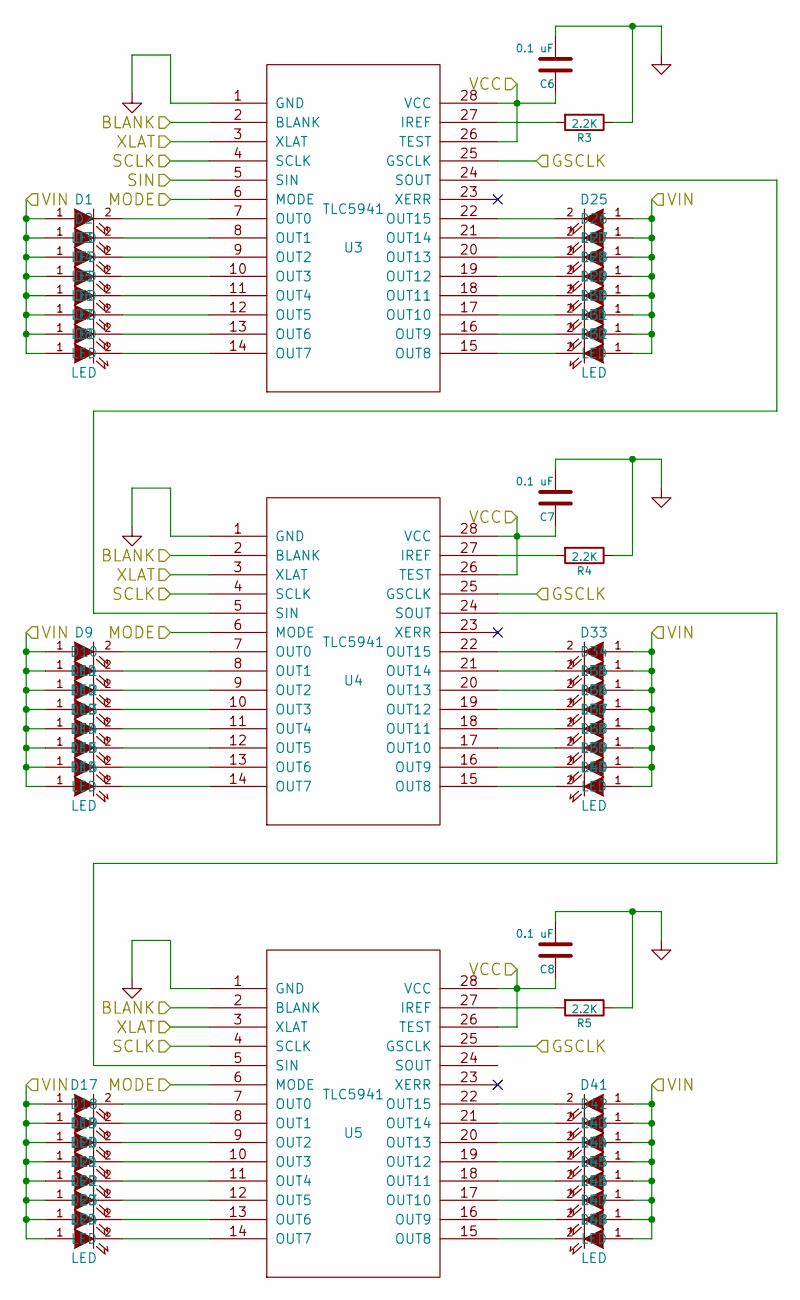
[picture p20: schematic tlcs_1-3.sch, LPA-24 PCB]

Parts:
C6, C7, C8: 0.1 uF; SM0805
D1, D2, D3, D4, D5, D6, D7, D8, D9, D10, D11, D12, D13, D14, D15, D16, D17, D18, D19, D20, D21, D22, D23, D24, D25, D26, D27, D28, D29, D30, D31, D32, D33, D34, D35, D36, D37, D38, D39, D40, D41, D42, D43, D44, D45, D46, D47, D48: LED; PCV220_LED_SOCKET
R3, R4, R5: 2.2K; SM0805
U3, U4, U5: TLC5941

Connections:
/tlcs_1-3/BLANK: U3.2 (BLANK), U4.2 (BLANK), U5.2 (BLANK); also elsewhere on the board
/tlcs_1-3/GSCLK: U3.25 (GSCLK), U4.25 (GSCLK), U5.25 (GSCLK); also elsewhere on the board
/tlcs_1-3/MODE: U3.6 (MODE), U4.6 (MODE), U5.6 (MODE); also elsewhere on the board
/tlcs_1-3/SCLK: U3.4 (SCLK), U4.4 (SCLK), U5.4 (SCLK); also elsewhere on the board
/tlcs_1-3/SIN: U3.5 (SIN); also elsewhere on the board
/tlcs_1-3/VCC: C6.1, C7.1, C8.1, U3.26 (TEST), U3.28 (VCC), U4.26 (TEST), U4.28 (VCC), U5.26 (TEST), U5.28 (VCC); also elsewhere on the board
/tlcs_1-3/VIN: D1.1 (A), D2.1 (A), D3.1 (A), D4.1 (A), D5.1 (A), D6.1 (A), D7.1 (A), D8.1 (A), D9.1 (A), D10.1 (A), D11.1 (A), D12.1 (A), D13.1 (A), D14.1 (A), D15.1 (A), D16.1 (A), D17.1 (A), D18.1 (A), D19.1 (A), D20.1 (A), D21.1 (A), D22.1 (A), D23.1 (A), D24.1 (A), D25.1 (A), D26.1 (A), D27.1 (A), D28.1 (A), D29.1 (A), D30.1 (A), D31.1 (A), D32.1 (A), D33.1 (A), D34.1 (A), D35.1 (A), D36.1 (A), D37.1 (A), D38.1 (A), D39.1 (A), D40.1 (A), D41.1 (A), D42.1 (A), D43.1 (A), D44.1 (A), D45.1 (A), D46.1 (A), D47.1 (A), D48.1 (A); also elsewhere on the board
/tlcs_1-3/XLAT: U3.3 (XLAT), U4.3 (XLAT), U5.3 (XLAT); also elsewhere on the board
GND: C6.2, C7.2, C8.2, R3.1, R4.1, R5.1, U3.1 (GND), U4.1 (GND), U5.1 (GND); also elsewhere on the board
unnamed: D1.2 (K), U3.7 (OUT0)
unnamed: D2.2 (K), U3.8 (OUT1)
unnamed: D3.2 (K), U3.9 (OUT2)
unnamed: D4.2 (K), U3.10 (OUT3)
unnamed: D5.2 (K), U3.11 (OUT4)
unnamed: D6.2 (K), U3.12 (OUT5)
unnamed: D7.2 (K), U3.13 (OUT6)
unnamed: D8.2 (K), U3.14 (OUT7)
unnamed: D9.2 (K), U4.7 (OUT0)
unnamed: D10.2 (K), U4.8 (OUT1)
unnamed: D11.2 (K), U4.9 (OUT2)
unnamed: D12.2 (K), U4.10 (OUT3)
unnamed: D13.2 (K), U4.11 (OUT4)
unnamed: D14.2 (K), U4.12 (OUT5)
unnamed: D15.2 (K), U4.13 (OUT6)
unnamed: D16.2 (K), U4.14 (OUT7)
unnamed: D17.2 (K), U5.7 (OUT0)
unnamed: D18.2 (K), U5.8 (OUT1)
unnamed: D19.2 (K), U5.9 (OUT2)
unnamed: D20.2 (K), U5.10 (OUT3)
unnamed: D21.2 (K), U5.11 (OUT4)
unnamed: D22.2 (K), U5.12 (OUT5)
unnamed: D23.2 (K), U5.13 (OUT6)
unnamed: D24.2 (K), U5.14 (OUT7)
unnamed: D25.2 (K), U3.22 (OUT15)
unnamed: D26.2 (K), U3.21 (OUT14)
unnamed: D27.2 (K), U3.20 (OUT13)
unnamed: D28.2 (K), U3.19 (OUT12)
unnamed: D29.2 (K), U3.18 (OUT11)
unnamed: D30.2 (K), U3.17 (OUT10)
unnamed: D31.2 (K), U3.16 (OUT9)
unnamed: D32.2 (K), U3.15 (OUT8)
unnamed: D33.2 (K), U4.22 (OUT15)
unnamed: D34.2 (K), U4.21 (OUT14)
unnamed: D35.2 (K), U4.20 (OUT13)
unnamed: D36.2 (K), U4.19 (OUT12)
unnamed: D37.2 (K), U4.18 (OUT11)
unnamed: D38.2 (K), U4.17 (OUT10)
unnamed: D39.2 (K), U4.16 (OUT9)
unnamed: D40.2 (K), U4.15 (OUT8)
unnamed: D41.2 (K), U5.22 (OUT15)
unnamed: D42.2 (K), U5.21 (OUT14)
unnamed: D43.2 (K), U5.20 (OUT13)
unnamed: D44.2 (K), U5.19 (OUT12)
unnamed: D45.2 (K), U5.18 (OUT11)
unnamed: D46.2 (K), U5.17 (OUT10)
unnamed: D47.2 (K), U5.16 (OUT9)
unnamed: D48.2 (K), U5.15 (OUT8)
unnamed: R3.2, U3.27 (IREF)
unnamed: R4.2, U4.27 (IREF)
unnamed: R5.2, U5.27 (IREF)
unnamed: U3.24 (SOUT), U4.5 (SIN)
unnamed: U4.24 (SOUT), U5.5 (SIN)

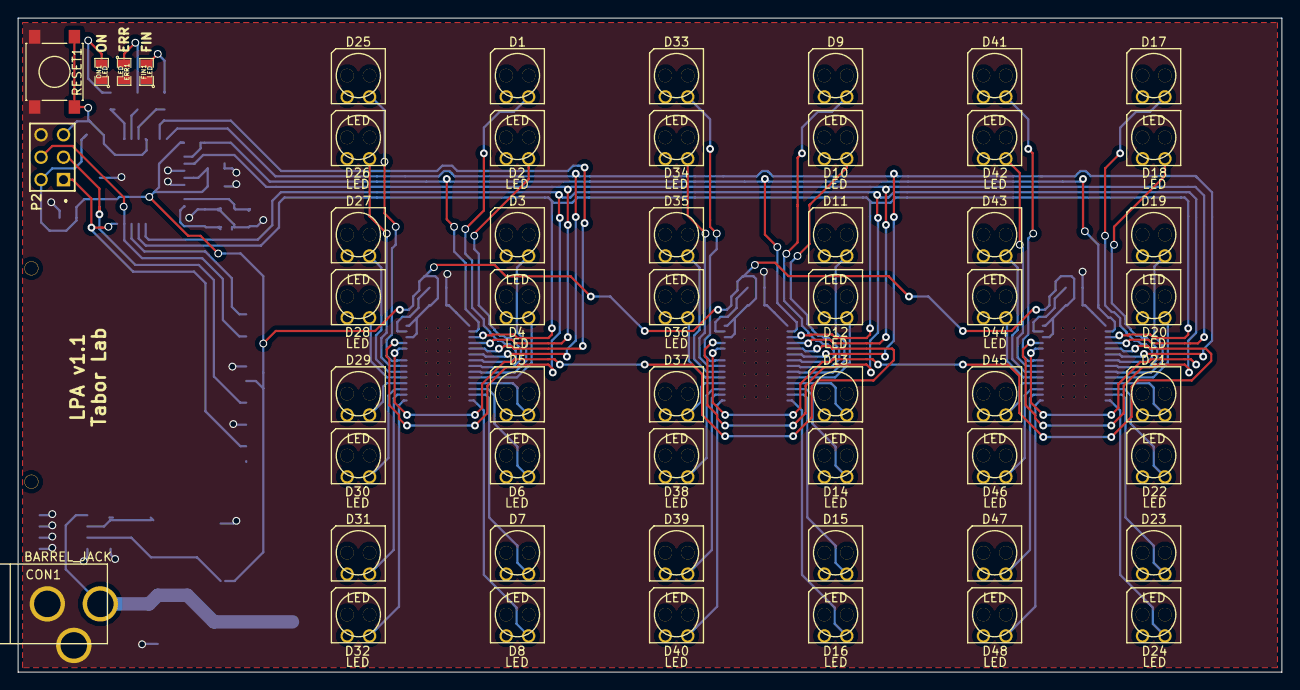
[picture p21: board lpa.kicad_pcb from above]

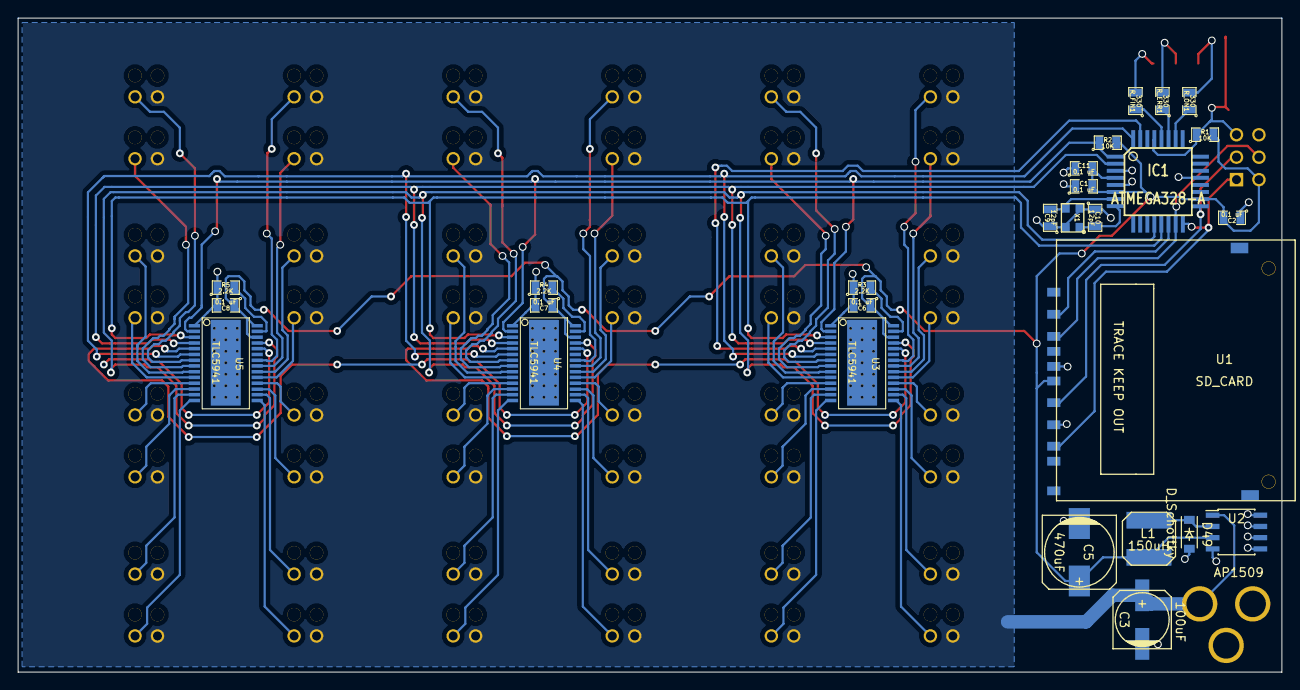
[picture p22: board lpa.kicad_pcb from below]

Board: 2 copper layers, 143.0 x 74.0 mm, 81 parts (27 on the bottom side), 76 nets.

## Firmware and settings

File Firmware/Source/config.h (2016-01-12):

/*
 * config.h
 *
 * Created: 03/03/2014 02:29:05 PM
 *  Author: Sebastian Castillo
 */ 

// Global configuration variables
#define F_CPU 16000000UL

// Configuration for Tlc5941 module
#define Tlc5941_GSCLK_DDR DDRB
#define Tlc5941_GSCLK_PORT PORTB
#define Tlc5941_GSCLK_PIN PB0

#define Tlc5941_XLAT_DDR DDRB
#define Tlc5941_XLAT_PORT PORTB
#define Tlc5941_XLAT_PIN PB1

#define Tlc5941_SIN_DDR DDRD
#define Tlc5941_SIN_PORT PORTD
#define Tlc5941_SIN_PIN PD1

#define Tlc5941_MODE_DDR DDRD
#define Tlc5941_MODE_PORT PORTD
#define Tlc5941_MODE_PIN PD2

#define Tlc5941_BLANK_DDR DDRD
#define Tlc5941_BLANK_PORT PORTD
#define Tlc5941_BLANK_PIN PD3

#define Tlc5941_SCLK_DDR DDRD
#define Tlc5941_SCLK_PORT PORTD
#define Tlc5941_SCLK_PIN PD4

#define Tlc5941_TIMER 2

#define Tlc5941_USART_SPI 1

#define Tlc5941_N 3

#define Tlc5941_MANUAL_DC_FUNCS 1

#include <avr/io.h>
#include <avr/pgmspace.h>
#include "Tlc5941/Tlc5941.h"

/*static const Tlc5941_gsData_t well2channel[Tlc5941_numChannels] PROGMEM = {
	0, 1, 2, 3, 4, 5, 6, 7, 8, 9, 10, 11,
	12, 13, 14, 15, 16, 17, 18, 19, 20, 21, 22, 23,
	24, 25, 26, 27, 28, 29, 30, 31, 32, 33, 34, 35,
	36, 37, 38, 39, 40, 41, 42, 43, 44, 45, 46, 47,};*/

static const Tlc5941_gsData_t well2channel[Tlc5941_numChannels] PROGMEM = {
	15, 14, 0, 1, 31, 30, 16, 17, 47, 46, 32, 33,
	13, 12, 2, 3, 29, 28, 18, 19, 45, 44, 34, 35,
	11, 10, 4, 5, 27, 26, 20, 21, 43, 42, 36, 37,
	9, 8, 6, 7, 25, 24, 22, 23, 41, 40, 38, 39,};
	
// Time step scaling
#define stepSizeScaling 1.0

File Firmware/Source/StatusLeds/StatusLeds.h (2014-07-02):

/*
 * StatusLeds.h
 *
 * Created: 18/06/2014 03:29:57 PM
 *  Author: Sebastian Castillo
 */ 

#ifdef __cplusplus
extern "C" {
#endif

#ifndef STATUSLEDS_H_
#define STATUSLEDS_H_

// LED identifiers
#define StatusLeds_LedOn 3
#define StatusLeds_LedErr 4
#define StatusLeds_LedFin 5

// LED status
#define StatusLeds_On 1
#define StatusLeds_Off 0

// Functions
void StatusLeds_Init(void);
void StatusLeds_Set(uint8_t led, uint8_t status);
void StatusLeds_Toggle(uint8_t led);

#endif /* STATUSLEDS_H_ */

#ifdef __cplusplus
}
#endif

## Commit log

2014-02-27 First, empty version of firmware.
    [tca.kicad_pcb, tca.sch]
2014-02-28 Added arduino TLC library to project, can compile but still doesn't work.
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2014-05-01 Modified board to include SD card and other improvements.
    [tca.kicad_pcb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]
2014-05-01 board folder is now board_24.
    [tca.kicad_pcb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]
2014-05-07 small gnd updates
    [tca_autorouted.dsn, tca_autorouted.kicad_pcb]
2014-05-07 Move a mounting pin
    [tca_autorouted.kicad_pcb]
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2014-05-24 Design which was submitted to OSHpark
    [tca_autorouted-B_Cu.dxf, tca_autorouted-B_Mask.dxf, tca_autorouted-Edge_Cuts.dxf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]
2014-06-16 Deleted unnecessary files and updated Tlc library.
    [tca.dsn, tca.kicad_pcb, tca_autorouted-B_Cu.dxf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]
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2014-07-02 Added synchronization and corrected bugs.
    [config.h]
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2014-07-08 Corrected bug in calibration-mode grayscale assignment.
    [config.h]
2014-07-10 Corrected bugs and added a static TF compiling mode.
    [StatusLeds.h, config.h]
2014-07-10 Made board_24_v2 which uses PCB-mounted LED sockets and updated various issues on board_96 as well. These PCBs were ordered around 7/1/14.
    [board_24v2_BOM.xlsx, board_96_BOM.xlsx, tca.kicad_pcb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]
2014-07-10 Eliminated duplicate board_24 folder.
    [board_24_BOM.xlsx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]
2014-07-11 Fixed calibration multiplication bug and transfered some constants to program memory.
    [config.h]
2014-08-04 Added config files for 24 and 96wp, corrected first-frame delay bug.
2014-08-07 Added ability to set dot correction via config.h.
    [config.h]
2014-09-04 Added ability to change individual dot correction values in config.h
    [config.h]
2015-02-23 Added structure files for the 96-well device.
    [96_plate_adapter.SLDPRT, 96_plate_bottom_fan.SLDPRT, 96_plate_top.SLDPRT]
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2015-11-08 Deleted the structure_96 folder.
    [96_plate_adapter.SLDPRT, 96_plate_bottom_fan.SLDPRT, 96_plate_top.SLDPRT]
2015-11-08 Moved folders with 3d-printed parts and laser-cut gaskets.
    [LED_socket_aligner_v0.5.SLDPRT, LED_socket_aligner_v0.5.STL, LED_spacer_v0.25.SLDPRT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]
2015-11-08 Removed 96-well electronic CAD files.
    [board_96_BOM.xlsx, tca.kicad_pcb, tca.sch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]
2015-11-08 Renamed electronic CAD folder.
    [board_24_BOM.xlsx, tca.kicad_pcb, tca.sch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]
2016-01-12 Corrected incorrect ordering of status leds.
    [StatusLeds.h]
2016-01-12 Added the ability to read dot correction and grayscale calibration values from a textfile.
    [config.h]
2016-01-12 Changed names of electronics CAD files from tca to lpa.
    [lpa.kicad_pcb, lpa.sch, tlcs_1-3.sch]
2016-01-12 Changed the orientation of the leds in the electronic board.
    [lpa.kicad_pcb]
2016-01-12 Changed the orientation of the programming connector.
    [lpa.kicad_pcb]
2016-01-12 Added pin 1 indicator on programming connector.
    [lpa.kicad_pcb]
2016-01-13 Moved status LEDs to fit with the 3d-printed parts.
    [lpa.kicad_pcb]
2016-01-14 Changed board to use quartz oscillator.
    [lpa.kicad_pcb, lpa.sch, tlcs_1-3.sch]
2016-01-14 Improved footprint of TLCs.
    [lpa.kicad_pcb, tlcs_1-3.sch]
2016-01-14 Streamlined library files for the electronic schematic.
    [lpa.kicad_pcb, lpa.sch, tlcs_1-3.sch]
2016-01-14 Assigned footprint to LED sockets.
    [lpa.kicad_pcb, tlcs_1-3.sch]
2016-01-15 Streamlined layout libraries.
    [lpa.kicad_pcb, lpa.sch, tlcs_1-3.sch]
2016-01-15 Changed reset button layout for standard library item.
    [lpa.kicad_pcb, lpa.sch]
2016-01-15 Changed myParts library to LPA_parts.
    [lpa.sch, tlcs_1-3.sch]
2016-01-15 Changed orientation of error LED.
    [lpa.kicad_pcb, lpa.sch]
2016-01-15 Removed pullup resistors from SD card socket.
    [lpa.kicad_pcb, lpa.sch]
2016-01-20 Added one more decoupling resistor to uC.
    [lpa.kicad_pcb, lpa.sch]
2016-01-20 Replaced power connector by barrel jack.
    [lpa.kicad_pcb, lpa.sch]
2016-01-21 Changed power supply circuit.
    [lpa.kicad_pcb, lpa.sch]
2016-01-21 Added VIN plane to PCB layout.
    [lpa.kicad_pcb]
2016-01-23 Moved power circuit to the back entirely.
    [lpa.kicad_pcb, lpa.sch, tlcs_1-3.sch]
2016-01-23 Changed barrel jack pads to circular.
    [lpa.kicad_pcb, lpa.sch]
2016-01-25 Small modifications to PCB silkscreen.
    [lpa.kicad_pcb]
2016-02-16 Changed names of kicad files.
    [lpa.kicad_pcb, lpa.sch, tlcs_1-3.sch]
2016-02-17 Removed STL files from 3D printed parts directory.
    [LED_socket_aligner_v0.5.STL, LED_spacer_v0.25.STL, flow_tube_holder_v3_bottom.STL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]
2016-03-04 Changed name of folder with electronic CAD files.
    [lpa.kicad_pcb, lpa.sch, tlcs_1-3.sch]
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2016-10-25 Publication 3D printed, gasket, and calibration files
    Updated 3D printed files with "decompensated"/"publication" versions for
    commercial printing.
    Updated gasket folder to include the pololu set.
    Introduced "calibration" folder with example .dc and .gcal files, image
    analysis calibration script, and example image analysis calibration
    session files.
    [LED_socket_aligner_v0.5.SLDPRT, LED_socket_aligner_xomv0.5.SLDPRT, LED_spacer_v0.25.SLDPRT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]
2016-10-25 Changed name of LED calibration folder.
    [calibration_round_ch2_n1.csv, round1_raw.csv, round1_rel.csv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]
2016-10-26 Restored solidworks files calibrated for the Tabor lab's 3D printer.
    [LED_socket_aligner_v0.5.SLDPRT, LED_socket_aligner_xomv0.5.SLDPRT, LED_spacer_v0.25.SLDPRT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]
2016-10-27 Modified mounting plate 3d-printed part.
    [mounting_plate.SLDPRT, mounting_plate_v0.3.SLDPRT, mounting_plate_v0.3_savage_30C.SLDPRT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]
2016-10-27 Added additional configurations on 3d printed parts for new LED aligner.
    [LED_spacer_v0.25.SLDPRT, mounting_plate.SLDPRT]
2016-10-27 Removed version numbers from 3d-printed parts file names.
    [LED_socket_aligner.SLDPRT, LED_spacer.SLDPRT, flow_tube_holder_bottom.SLDPRT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]
2016-10-28 Increased height of mounting plate to fit new capacitor.
    [mounting_plate.SLDPRT]
2017-06-08 Updated LED socket aligner to match current board.
    [LED_socket_aligner.SLDPRT, LED_socket_aligner_bottom.SLDPRT, LED_socket_aligner_top.SLDPRT]
2017-06-08 Updated LPA version in board silkscreen.
    [lpa.kicad_pcb]
2017-06-08 Reorganized LED calibration folder.
    [calibration_round_ch2_n1.csv, round1_raw.csv, round1_rel.csv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]
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2017-06-15 Added Circuit Board files for production.
    [LPA_BOM.xlsx, LPA_component.xlsx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]
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2019-08-09 Reorganization, housekeeping, minor chassis changes.
    Reorganized folders/files to conform with MIE chapter.
    Added solder paste files.
    Updated BOM which contained several discontinued parts.
    Fuses.txt: "CKOUT" -> "Enable CKOUT"
    3D printed parts: Reverted most files to the publication version (which were "decompensated" to print accurately on printers outside the Tabor lab). Mounting plate file from Release v.1.1 decompensated to print correctly on outside printers (given version 0.5, not validated). Removed screw holes from LED socket aligner, the use of which is deprecated. Replaced plate lid with holes above wells with frame-type lid.
    [Chassis BOM.xlsx, Component Placement.xlsx, LED_socket_aligner_bottom.SLDPRT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]
